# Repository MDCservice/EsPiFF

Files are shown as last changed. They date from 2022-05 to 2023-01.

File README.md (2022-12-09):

# EsPiFF
An ESP32 in the Raspberry Pi form factor

## Meet the EsPiFF - The ESP32 in the Raspberry Pi 4 form factor

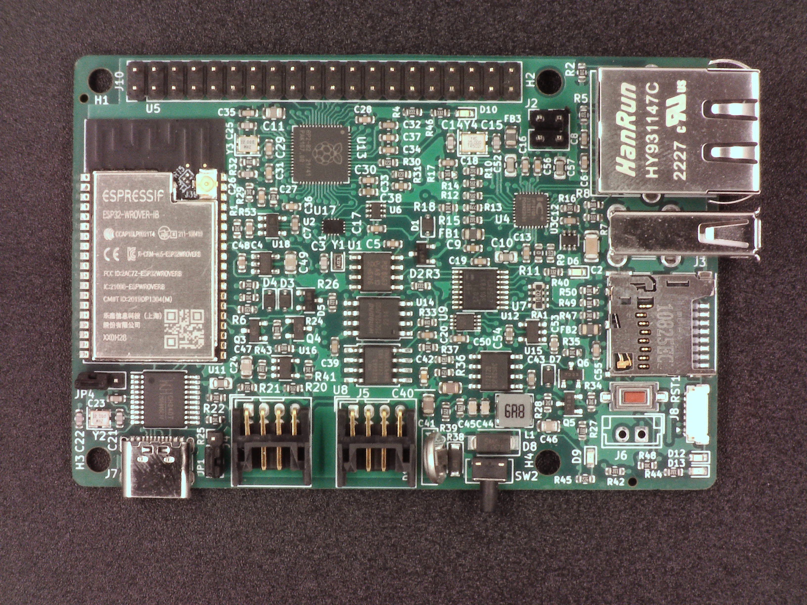
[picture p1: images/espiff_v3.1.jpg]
The EsPiFF


For applications, where the Raspberry Pi 4 is not robust enough, or take too much power, you can consider the EsPiFF as an option.
The EsPiFF (V2) brings
 - ESP32-WROVER with dual core, 8MB PSRAM, 16 MB Flash
 - Ethernet wired and Wifi (Wifi need an external antenna with an uFL connector)
 - SD-card for data storage
 - up to 3 UARTs
 - an USB-C connector for power supply up to 5V, 3A
 - a Rasperry Pi header with 40 pin, compatible to all Raspberry Pi HATs

The EsPiFF V3 will bring the following 
 - an RP2040 IO-processor additional to the ESP32
 - 2kByte FRAM for high-speed permanent storage
 - RTC Realtime clock
 - USB-A connector for USB-Host

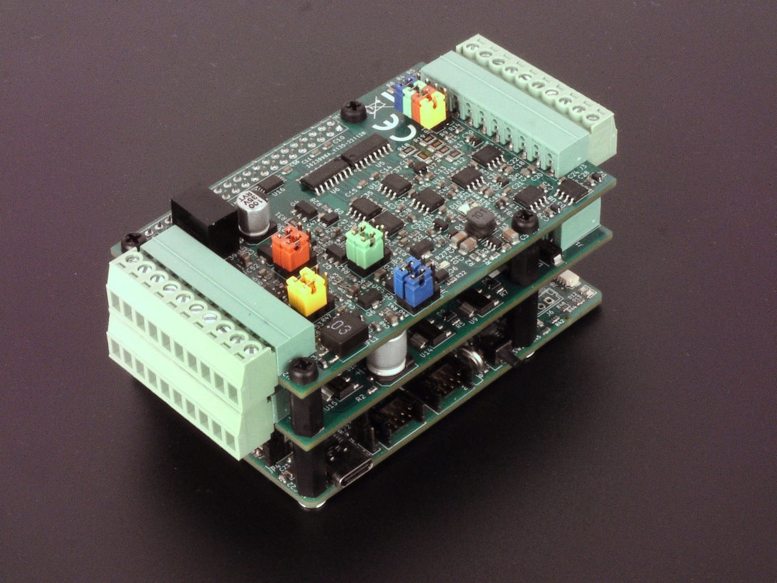
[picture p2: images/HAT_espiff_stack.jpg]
HAT_dio

EsPiFF-PLC

## Why an ESP32 in the Raspberry Pi Form Factor?

We decided to build an alternative to the Raspberry Pi for our projects and products. As many others we were using the Raspberry Pi in our products, adding electronic payment to existing vending machines and coffee machines, in RFID solutions to read RFID tags in laundry and other application. 
While it was easy to get a solution up and running in a short time, over time we got a lot of problems resulting from using the Pi.
A key problem of the Pi's design is, to rely on an SD-card. The SD-cards are made for digital cameras, to write on them a few times. A Linux system like the Pi on the other hand, is writing permanent its log files and swap partition or to the SD-card. As a result, after some months the SD-card broke and the application crashed. High-end industrial SD-card lasted longer, but finally still broke. An industrial controller simply can not base on a SD-card.
The PI Operating system is also great for fast bring-up of a solution, but its more and more focused on media streaming then real-time tasks. It gets more and more overloaded with each new version.
So we made the decision, to build a replacement, which is focused on high-reliability, but still enable the use of Raspberry Pi universum of add-ons, like HATs and enclosures. We choose the ESP32 dual core, 2x240MHz WROVER module with 8MB PSRAM and 16MB Flash.  The EsPiFF, the **Es**p32 in Raspberry **Pi** **F**orm **F**actor was born.

## History
### Version 1
The first version of the EsPiFF was born in a time, where all Ethernet Phy chips was unavailable. Our first prototype used a Waveshare LAN8720 module. Chip crysis! Interestingly, even no LAN8720 chips could be bought anywhere, but the modules was still available. Because the Waveshare module did not route the enable signal to the pin header, but left one pin unconnected on the pin header, we had to solder a wire from the oscillator to that unused pin on the header. After these, the board run well, and do so till now. We added 4 high side switches, and digital inputs to operate 4 door locks. These are the 4 white connectors opposite the RJ45 connectors. The Version 1 had the WROOM module of the ESP32.  

Picture: the Version 1 of the EsPiFF

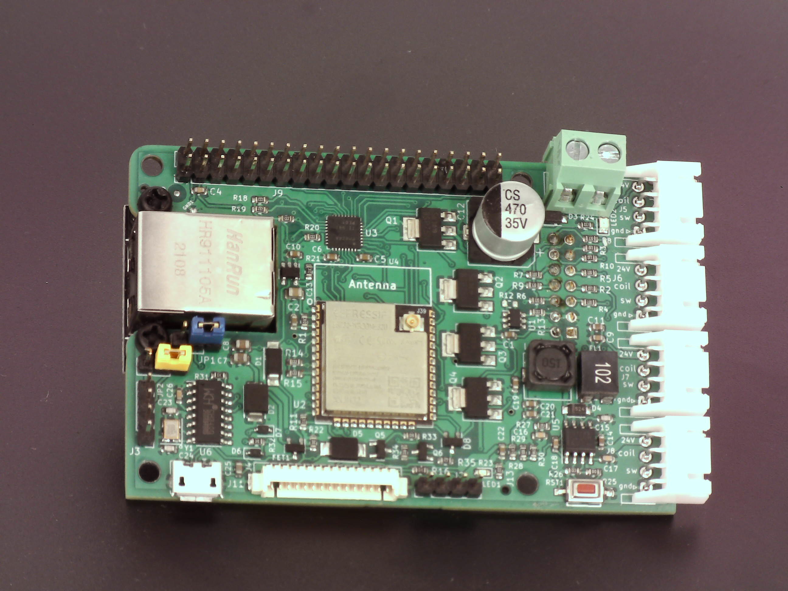
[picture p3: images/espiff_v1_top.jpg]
The Version 1


We ported the PostgreSQL client libray, based on [SimplePgPSQL](https://github.com/ethanak/SimplePgSQL) to the EsPiFF, what worked very well, even with the limited RAM and Flash. Not only SELECT, INSERT and UPDATE work, but also the brilliant PostgreSQL feature NOTIFY. As a result, the EsPiFF dont need to poll the PostgreSQL server, but get notified instead. We could define a trigger in PostgreSQL, and notify other EsPiFF board. Thats very cool.

Because of the ongoing chip crysis, we only select parts, what are available. 

### Version 2

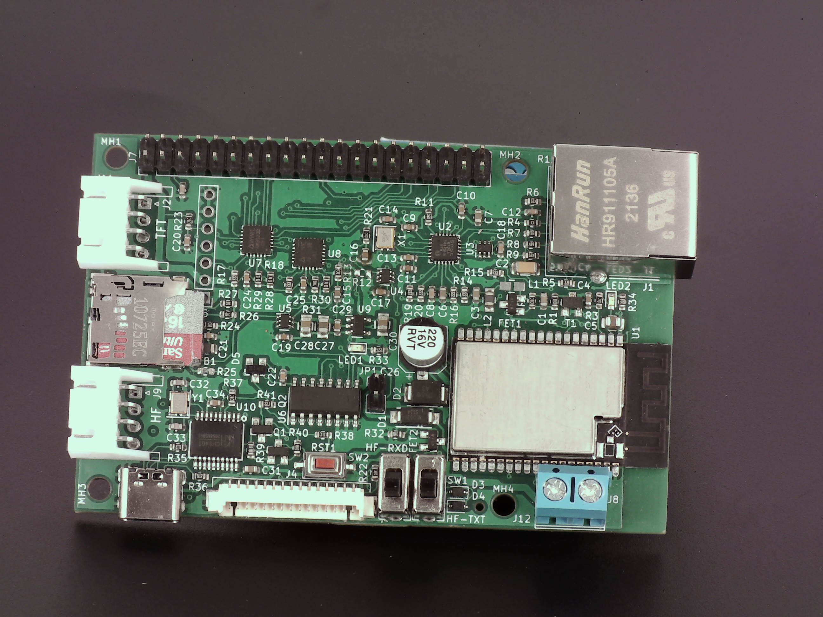
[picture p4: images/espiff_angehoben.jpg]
The Version 2
 
After the LAN8720 chips got available again, we decided to make a new board revision. These are the current boards. We used the ESP32-WROVER module, for additional 8MB PSRAM and 16MB Flash. We also added an SD-card. Unfortunately, we used the wrong pinout, make it very difficult to change the SD-card. An other issue was a missing pull-up resistor on the LAN8720. 
We changed the USB connector to a Type-C connector, and configured it so, that 5V and up to 3A can be taken. Thats a big improvement, raising the available power from 0.5W to 15W. We removed the 4 door lock connectors, and put them on a HAT. 
Since version 1 we have a "Chafon-Connector", next to the USB connector. It is to connect the Chafon RFID Rain(UHF) modules. Additional, we replaced the UART pin headers with more robust JST connectors, left and right of the SD-card. 

We could also compile and flash the Apache Nuttx operating system on the new board. A growing number of people are using ESP32-WROVER boards together with Nuttx as OS. This offers an somehow easy path of porting Linux and Raspberry Pi software on ESP32+Nuttx. 

### Version 3
This is the planned final version. Additional to the fix of the 2 known issues, we plan the following:
 - adding a I2C-RTC: a real-time clock will be needed for planned PLC usage.
 - adding a 2kByte FRAM: again for PLC application, a fast and non-volatile memory is needed. It offers near infinity write/read cycles compared to flash.
 - replace the WROVER module with a version with u.FL/IPEX connector. This enables an external antenna, longer range, mounting inside a metal enclosure with the antenna outside the enclosure.
 - adding a RP2040 co-processor. The ESP32 just not have enough pins free, to operate all the pins on the Raspberry Pi 40pin header. The last solution with the I2C port expander is too slow and unflexible. The much more powerfull RP2040 will solve these problem. It also offers an USB host port!
 - add a USB-A connector, to program the RP2040, and to enable to connect USB devices like keyboard, mouse, USB-sticks and so on. 
 - add an HMI connector next to the SDcard socket. This is for our upcomming TFT displays, but can be used for UART based TFTs like the Nextion as well. 

This is the current progress. We managed, to bring all the functionality on the board. We selected a 6 layer PCB, for best signal integrity.

The ESP32 can communicate with the RP2040 via SPI, where the ESP32 is the SPI master. Depend on the requirements, the communication protocol can be implemented application specific, with ether the Espressif IDF or Arduino IDE. Or an existing SPI driver from, for example NuttX, could be used on the ESP side, and the RP2040 emulating for example an SD card or a SPI Flash.

One more option is to run [Firmata](https://github.com/firmata/ConfigurableFirmata) on the RP2040. This is a popular way for Arduino developers, to remote control and Arduino/RP2040 from a host computer, here the ESP32. For now, Firmata only supports UART communication, whats is also possible on the EsPiFF.

Because all pins on both the ESP32 and the RP2040 are used already, there are no decidated interupt pins between ESP32 and RP2040. The software should implement software interupts, when i.e. the receiving buffer reaches a certain level. 

The Version 3

We finally replaced the LAN8720 Ethernet PHY by an IP101, as used in the Espressif Ethernet reference design. The LAN8720 showed stability problems, in combination with the ESP32-WROVER (it is working well with the ESP32-WROOM). Other projects with the ESP32-WROVER - LAN8720 combination (wESP, Olimex) seem to had the same problems, and also switched away from the LAN8720. On this point, a big "Thank you" to Ondrej from Espressif for all of his support in this field. 

We also ordered customized cables, for the DF11 and display connectors, what offer DuPont on the opposite side. With these cables, breadbord or Nextion displays, or other 2.54mm headers can easily connected. 

## Typical applications

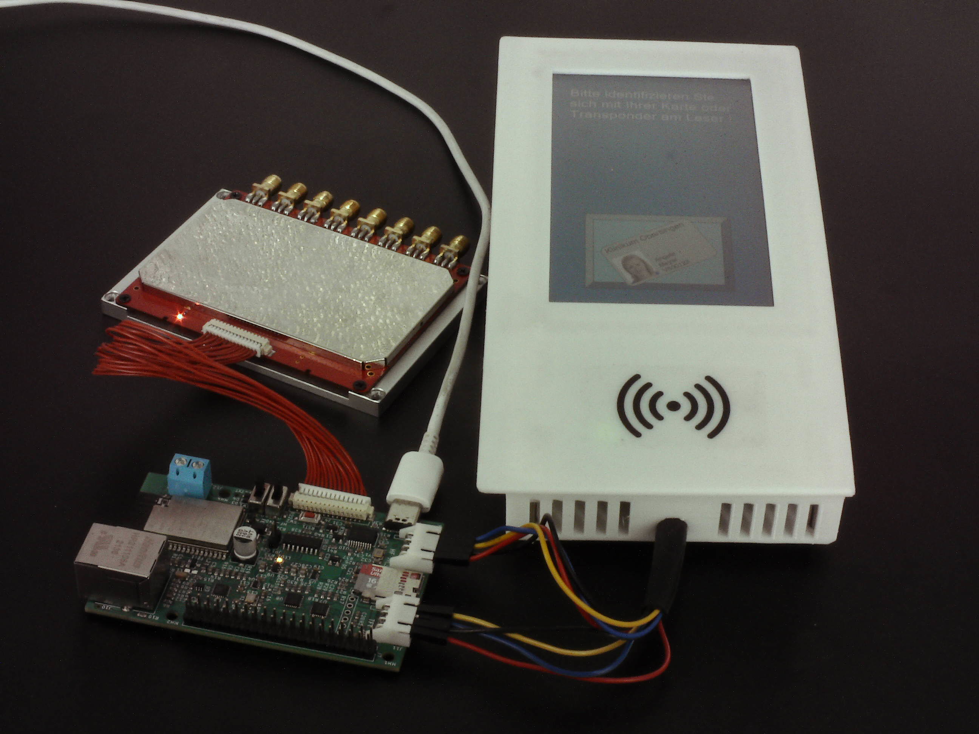
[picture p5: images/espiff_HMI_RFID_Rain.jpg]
HMI, RFID reader and EsPiff-V2


This example show, how a Nextion 5 inch TFT, a HF RFID reader from Elatec (TWN4), a Chafon 8 channel RAIN UHF-RFID reader and a 3D printed enclosure can form an electronic identification system. We put the source code and the 3D design files into the example folder. Smaller or bigger Nextion TFTs can be used, when you adapt the 3D design. 

The HMI interact with the user, ask him/her to put the HF-RFID card on the card reader. The TWN4 from Elatec is able to read near any LF or HF card, inclding the LEGIC chips used in many high secure access control applications. The TWN4 is inside the 3D printed enclosure, as well as the Nextion TFT.

With the 8 port RAIN UHF reader/writer from Chafon, we can monitor a whole area with up to 8 antennas. We use it to monitor 4 cabinets, other use cases could be the monitoring a whole room/warehouse, or the entrance of buiildings,etc. Chafon offer 1, 4, 8 and 16 port devices, and they are all compatible with the software. 

In our application, we read/write direct to a PostgreSQL database, connected by wired ethernet, thats why we have ported the LibPQ (the PostgreSQL client library) to the ESP32. The use of other techniques, like MQTT, is also possible. 

Picture: the open 3D printed enclsure, showing the Nextion 5'' TFT, and the TWN4 HF RFID reader
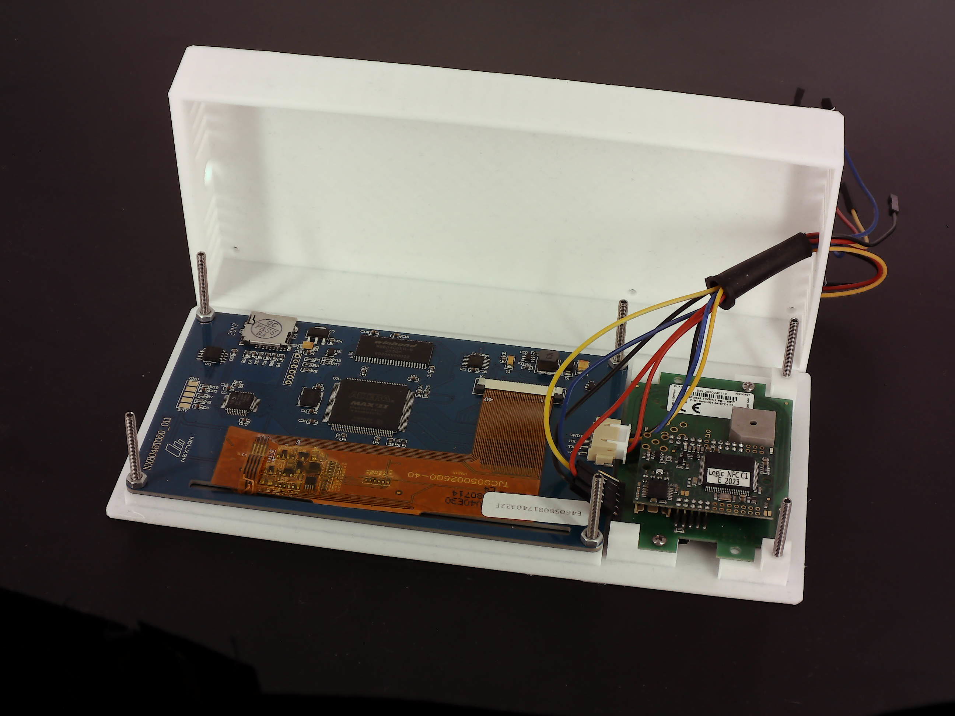
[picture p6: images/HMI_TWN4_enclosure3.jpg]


After the EsPiFF is now mature enough, we we are preparing a campaign at Crowd Supply. After the Pre-launch page will be available, we will update the info here. Hope you support us on our Crowd Supply campaign!

Please notice, that the ESP32-module PCB antenna can not be used, an external wifi antenna is required. This is because of space restrictions, the RasPi form factor not allow us to make the board larger, and there is simply no space left for the required keepout area for the PCB antenna. Most people will use a metal enclosure, what renders a PCB antenna useless anyway. We still have to use an ESP32-WROVER module containing a PCB antenna, because only these modules have 16 MB Flash, 8 MB PSRAM, and all the features we build in. Other modules, for example the ESP32-S3, does not have Ethernet MII. 

Apache Nuttx can run on the EsPiFF!
Next the wellknown FreeRTOS, there is an other, not so wellknown operating system supporting ESP32 and friends: Apache Nuttx (https://nuttx.apache.org).
It has a very cool feature: runtime loading of ELF files (for example, from SDcard) into RAM, and then execute it in RAM. Very much like Windows/Linux/MacOS are doing it. Imagine, you can send a SDcard to your customer for software-update. Bye bye over the air(OTA) updates in enviroments, where OTA is not allowed.

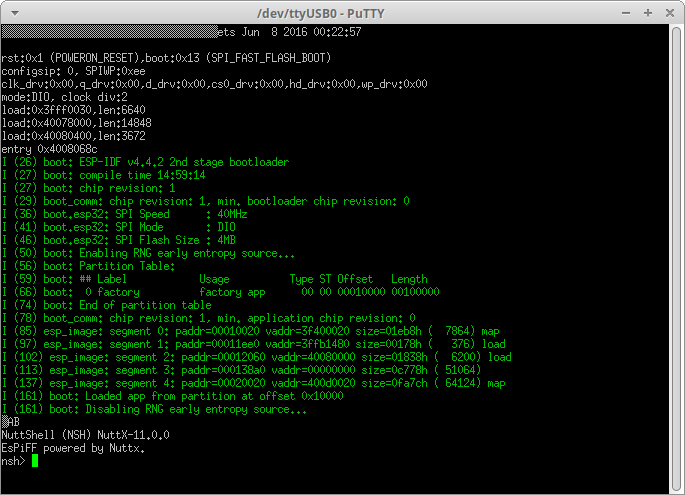
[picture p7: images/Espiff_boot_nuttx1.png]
Nuttx 11.0 on EsPiff-V3.1


ESP32 <> RP2040 interconnection

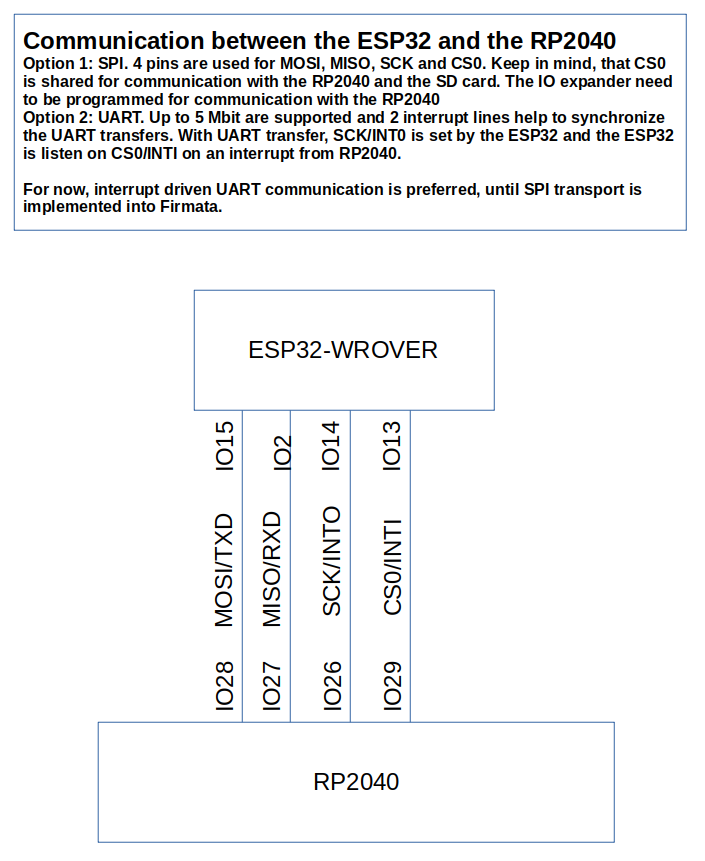
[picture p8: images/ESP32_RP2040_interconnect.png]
ESP32 <> RP2040


Latest news:
We just finish the layout of the version 3.2, the version the crowd supply backer will get. Few interesting things:
- We added not only Flash footprints for the ESP32, but also a footprint for an unpopulated SPI RAM for the RP2040. If you need up to 64 MBit SPI RAM for the RP2040, you can just mount an easy to solder SOIC-8 IC on the bottom, and you have 30 times(!) the RAM a normal RP2040 have. 

Because several people mention the integrated PCB antenna, the version 3.2 offer at least a basic use of the PCB antenna. Still, the external PCB antenna is the prefered way to use Wifi with the EsPiFF, now to use the integrated PCB antenna as well. 
Keep in mind, that the ESP32-WROVER-IB module requires a solder jumper modification before the PCB antenna can be used. 
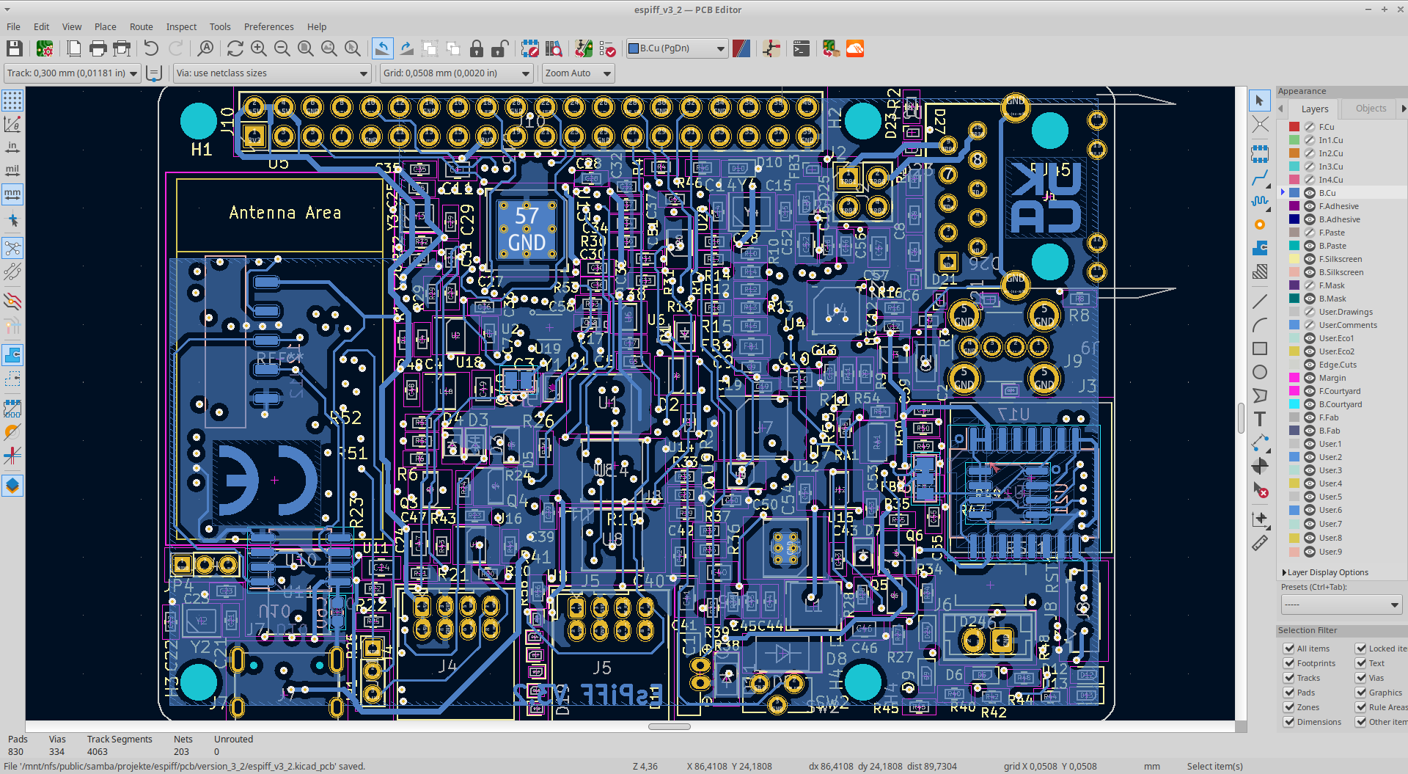
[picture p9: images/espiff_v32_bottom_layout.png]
ESP32 Wifi


Team MDC

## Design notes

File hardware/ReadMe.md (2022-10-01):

Hardware V3.1

This is the final schematic and layout for the Crowd Supply campaign.
The LAN8720 Ethernet PHY got replaced by the IP101, after the LAN8720 in combination with the ESP32-WROVER was not working stable.
Additionally, we added an TFT-Display connector for serial displays/HMIs.

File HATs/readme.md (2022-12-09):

**HATs for the EsPiFF**

****Digital IO HAT****
DIO

The Digital IO HAT offers 8 individual configurable digital inputs or outputs. Each of the 8 DIO pins can be configured by software to be ether an digital output with up to 1.2A, or an digital input for voltages from 3.3V to 30 Volt. All inputs and outputs are protected against over-voltage, over-current and over-temperature, additional protection for voltage spikes(up to 4kV) and static discharge is build in as well. 

Inputs can be read with up to 1 MSps, the outputs can be set with up to 6kHz. The digital IO part is complete galvanic isolated from the EsPiFF, with 6mm creepage distance between the logic part and IO part. 

With an external 24V power supply, the digital HAT powers it self and the EsPiFF(or Pi Nano). If no external power is supplied, the digital HAT receive its power from the EsPiFF(or Pi Nano).

The Digital IO HAT is made particular for the EsPiFF, because of its shape it can not be used with an Raspberry Pi 2/3/4. But it can be used with a Raspberry Pi Nano or Nano 2, and several Raspberry Pi clones. 

The 40 pin connector is build with extra long pins, so that an additional HAT can be stacked on it

****Analog IO HAT****
HAT_4ain_4aout

The analog IO HAT offers 4 analog inputs and 4 analog outputs. Each input and output can be jumper configured for ether 4-20mA or 0-10V signals. The analog inputs are synchronous sampled by 16 bit ADCs, the analog outputs are synchronous set by 12 bit DACs. 

The ADCs are build by analog-to-PWM converters, to allow syncron sampling and save galvanic isolation. For the same reason, the DACs are build by PWM-to-analog converters. This offers the unique feature, that all analog inputs and outputs can be synchronous set with ns accuracy, what typical SPI or I2C based  converters can never offer. To read and set the converters, 4 PWM cannals, and 4 Pulse width measurement units are needed. This is a perfect job for the PIOs of the EsPiFF. A Raspberry Pi offer only 2 (hardware) PWM channels, so a PI would not be a good platform for this kind of converters.

Extra care has been taken to implement a low noise power supply: a galvanic isolated PSU module generates 15 Volt. A team of ferrite beads, common mode chokes and ultra low noise linear regulators filter out all noise from the switching regulators and outside world. Only this very careful design enables 15 bit net out of the 16 bit ADCs.  

****EsPiFF-PLC build from a EsPiFF, an digital and an analog HAT****
HAT_espiff_stack

With the analog and digital HAT, an EsPiFF transforms to a nice PLC. It is compact in size, low in price and profit from the EsPiFF reliability features.

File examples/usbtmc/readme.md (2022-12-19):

Convert every HAT to an USBTMC-Measurement device with the EsPiFF. 

** work in progress, might not compile on all platforms. We use Ubuntu 22 for development **

Instructions:
1. Download the Tinyusb github repo from https://github.com/hathach/tinyusb
2. Add a folder "espiff_usbtmc" under ./tinyusb/examples/device/
3. copy the files from EsPiFF/examples/usbtmc/ into the folder just created.
4. make sure, your PICO SDK is setup correctly.
5. follow the instructions from the TinyUSB repo to build.

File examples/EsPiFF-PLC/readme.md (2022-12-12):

**The EsPiFF-PLC**

Thanks to its reliability properties and its fast IO capacity, the EsPiFF is a great base for rock solid PLC (Pogrammable Logic Controller). We have made 2 HATs for the EsPiFF, what can be stacked on the EsPiFF, and an 3D printed enclosure, to use the EsPiFF as a PLC. Schematics for the digital HAT is here, for the analog HAT is here (Schematics are in alpha stage, because we could not yet test all functions).

To compare the EsPiFF-PLC with what the market offer, lets compare the EsPiFF-PLC with 2 popular PLCs, one from the Arduino base ([Industruino](https://industruino.com/)) and an other from Raspberry Pi base ([Pixtend](https://www.pixtend.de/pixtend-v2/hardware-v2) V2 -S-). We have worked with both of them, before we decided to make the EsPiFF. Finally, I added the brand new Arduino Opta for comparison.

We do not cover PLCs without C/C++ programming, because Ladder Logic/FBD/ST from companies like Siemens, ABB, Rockwell, Mitsubishi etc. is out of the scope for most makers. Also most of them require an initial investment of several thousand $$ for there proprietary IDE / tools, before you can even start. 

## Comparisons

| | EsPiFF-PLC | Industruino | Pixtend-V2 -S- | Arduino Opta |
| --- | --- | --- | --- | --- |
| **PLC processor** ~active  | RP2040 | ATSAMD21G | ATMega324A | STM32H747XI | 
| **Digital inputs** | Up to 8 | Up to 8 | 8 | 8 |
| **Digital outputs** | Up to 8 | Up to 8 | 4 | 0 |
| **Digital block isolated** | Yes | Yes | No | No |
| **Analog inputs** | 4 (16 bit) | 4 (18 bit) | 2 (10 bit) | up to 8 |
| **Analog outputs** | 4 (12 bit) | 2 (12 bit) | 2 (V only) | None |
| **Analog block isolated**  | Yes | Yes | No | No |
| **Relay outputs** | 2 | 0 | 4 | 4 |
| **Retain memory** | 2 kBytes | 0 | 32 Bytes | 0 |
| **External RTC** | Yes | Yes | Yes | unknown |
| **External supervisior** | Yes | No | No | unknown |
| **Buffered RTC** | Yes | No | Yes | unknown |
| **PLC processing** | 2x133 MHz | 48 MHz | 20 MHz | 240 MHz |
| **Ethernet** | Yes | External (via SPI) | Yes | Yes |
| **Price** | $169.00 | $272.72 | $279.21 | $177.10 |

Its clear, that both competitors have serious limitations: The Pixtend have no galvanic isolation, only 4 digital outputs, only 10 bit analog inputs and  analog output. So its impossible to drive 4 - 20mA actuators like proportional valves. The analog resolution with just 10 bit ADCs does not allow accurate measurements, what limit its usefulness to a few low resolution applications. 
While the Pixtend offers enoumous processing power on the Raspberry Pi side, the real time processing power is very limited by the 8 bit ATMega324. As a result, no more then 500 to 800 cycles per second are possible (In a PLC, in one cycle all inputs are read and all output are set). The analog inputs have a "Cut-off frequency of 275 Hz", so my guess would be the analog inputs are limited to 100-150Hz.  A demanding servo application can not be build with this. The Retain memory memory is only guarantied for 10.000 write operation, the datasheet discourage the use of it (the FRAM on the EsPiFF guaranties 10 billion write cycles!). Finally the Pixtend is closed source, and Pis are not available because of the chip shortage. 

The Industruino is simple, easy to program, have 4 analog input with 18 bit, 2 analog output (12 bit), 8 digital IOs (each can be input or output), external RTC. Sound good until now. But: 
- No battery or capacitor to keep the RTC when power is removed,  
- no external supervision, 
- you need to buy the external Ethernet module, to get Ethernet, a socket for an FRAM, SD card socket. 
- only for a few parts schematics are open source,  
- a single  ATSAMD21G with 48MHz, 32 kByte RAM, 256kByte Flash must do all the work.
- quit expensive for the little functionality
- can NOT be programmed in Python

What the Pixtend had too much on processing power, the Industruino have too little. When you run a Modbus server, the MCU is mostly busy with network traffic. 

When we see the 500 to 800 cycles on the Pixtend as slow, it gets even worse with the  Industruino: the ADC on the Industruino is a MCP3424 I2C, what offer 3.75 SPS (18 bits), 15 SPS (16 bits), 60 SPS (14 bits) and 240 SPS (12 bits). SPS means "Samples Per Second". There will be applications, what are possible within these limits. But hey, that can be done better.

Just for reference, lets also take a look at the brand new Arduino Opta. It does not have analog outputs, not even digital outputs, so its usefulness is very limited. The concept of the Opta with a dual core controller is good, to seperate IO processing from network processing. Having relays integrated into the PLC is not often used, for a good reason: Users can simply install as many relays they need on a Din Rail, and choose the exact relay type they need for the particular application. Then control the relay with a digital output of the relay.

DinRailRelay

The relays in the Opta are only SPST (single pole, single throw, 2 contacts each), but many applications need a 3 contact version to flip between NC and NO. If you look at the [DIN Rail relay selection on Mouser](https://www.mouser.de/c/electromechanical/relays-contactors-solenoids/general-purpose-relays/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), you see how many configurations are possible. Interesting to see, that Arduino move to closed source and pay-to-use software with there PLC products: "runtime activation for each device will require a license key". Bye bye open source Arduinos.  

We have 2 HATs for the EsPiFF, one analog and one digital HAT. Together with the EsPiFF, they form the ***EsPiFF-PLC***. At the moment, the hardware just arrived, the software need some time to arrive at the EsPiFF github. 

****EsPiFF-PLC****
HAT_espiff_stack

****digital IO HAT****
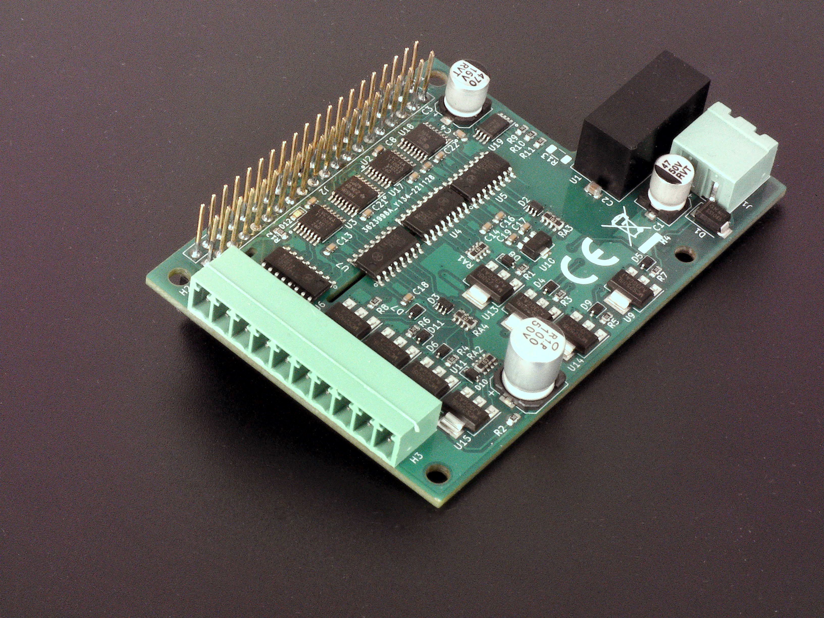
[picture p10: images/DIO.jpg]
HAT_dio


****analog IO HAT****
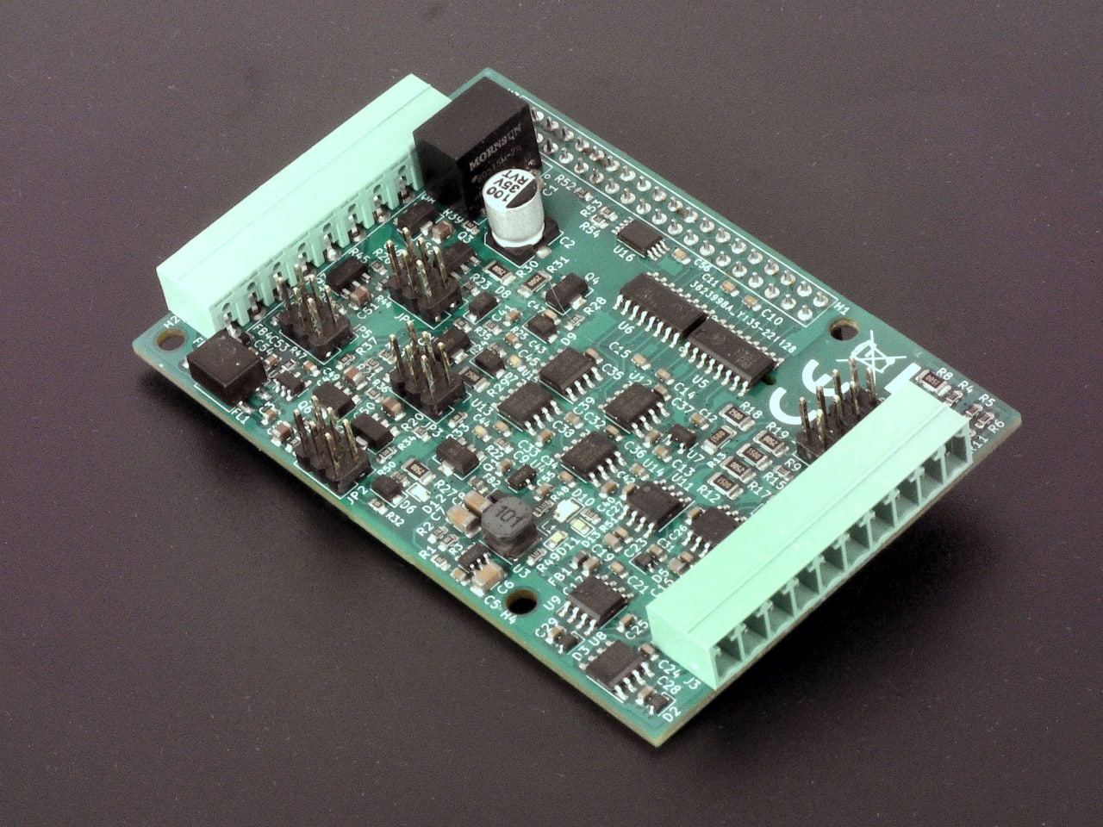
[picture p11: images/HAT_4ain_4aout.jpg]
HAT_analog


These 2 HATs are particular made for the EsPiFF: Even they could mechanically be mounted on a Raspberry Pi Nano, only the RP2040 PIOs have enough PWM channels and pulse-width measurement resources to operate the analog HAT. 

The HATs are stacked on the 40 pin Header, and are all controlled by the RP2040 from the EsPiFF. There is a detailed description about the HATs [on the EsPiFF github](https://github.com/MDCservice/EsPiFF/blob/main/HATs/readme.md), so I don't repeat that here.  Just the key facts:

4 analog in, jumper select-able for 0 to 10V or 4 - 20mA, fully protected.
4 analog out,  jumper select-able for 0 to 10V or 4 - 20mA, over-current, over-temperature, over-voltage protected.
All analog parts are galvanic isolated from the EsPiFF and the digital section.
8 digital IOs, each individual configurable as input or output, fully protected. As output, they can sink up to 1.2A permanent each, up to 32 Volt.  
All digital IOs are galvanic isolated from EsPiFF and from the analog section.  

The RP2040 as PLC-IO processor have multiple times the processing power, RAM and Flash, compared to the ATSAMD21G on the Industruino or the ATMega324 on the Pixtend. 16 MB Flash compared to 256kB(Industruino) or 32kB(Pixtend) result in 64/512 times bigger application. If the 16 MB additional SPI-RAM is soldered on the EsPiFF, the RP2040 on the EsPiFF have 512 times the RAM of an Industruino and 8192 times the RAM of the ATMega324 on the Pixtend.

Having the network stuff handled by its own processor unit, frees the PLC processor from these time consuming work. This is given on the EsPiFF-PLC by the ESP32, as well as on the Pixtend. But just the EsPiFF is build for reliability with external supervisior, external watchdog, and a real RTOS. 

Speed: we see, even with its enormous processing power of a Rasperry Pi, the Pixtend can maximal reach a cycle time of up to 800 per second. The Industruino is limited by its ADC to 240 cycles per second at low resolution ADC or 3.75 cycles per second at high resolution ADC. Here are the EsPiFF numbers:

- Digital inputs: up to 50.000  cycles per second.
- Digital outputs: up to 6.000 cycles per second.
- Analog inputs: up to 10.000 cycles per second. 
- Analog outputs: up to 50.000 cycles per second.

For the Pixtend, we know the limit of 800 cycles ([the Handbook suggest only 10Hz!](https://www.pixtend.de/files/manuals/AppNote_CodesysPiXtendProject_DE.pdf)), for the Industruino we [know the limit of 1380Hz](https://industruino.com/forum/help-1/question/speed-problem-on-i-o-board-100). Just in real world applications, the Industruino will not reach these limits, because as long as its answering network packages, the single core can not operate IOs at the same time. The unpredictable network processing load will also lead to unpredictable real time behavior. For the Arduino Octa, no data or experience are available.  

Finally, lets look at a typical PLC application: reading an 4-20mA transducer, performing a PID control algorithm, and set a new analog value on the 4-20mA output. I used to implement this exact scenario for a hydraulic pressure test bench a few years ago. An hydraulic pressure transducer transmitted a 4-20mA signal for the hydraulic pressure on the hose under test to the analog input, the pressure actor was commanded with an 4-20mA analog output and a PID control algorithm set the current test pressure. The Arduino Octa have no analog or digital outputs, so its out of the game here. Lets see, how many such control loops the EsPiFF-PLC and the 2 competitors can handle per second:  

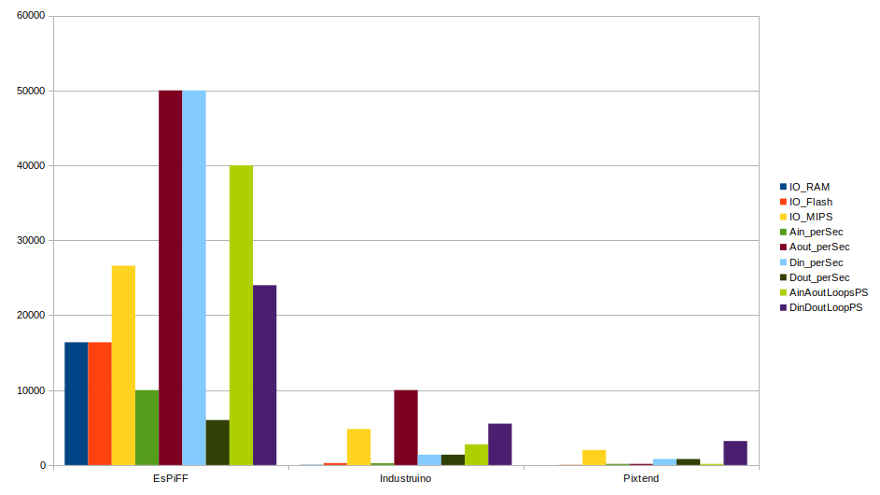
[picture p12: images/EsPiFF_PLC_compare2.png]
Compare_loops_perSecond


The EsPiFF-PLC is more then 14 times faster in analog processing then the Industruino; the Pixtend is out of this game because it does not offer an analog 4-20mA output. 
In a pure digital loop (read digital in, compute, set digital out), the EsPiFF is still more then 4 times faster then the Industruino and more then 7 times faster then the Pixtend. 

We hope, this article shows, how powerful the EsPiFF is.

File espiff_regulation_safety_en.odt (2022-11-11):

EsPiFF REGULATORY COMPLIANCE AND SAFETY INFORMATION

Product name: EsPiFF V3.2

IMPORTANT: PLEASE RETAIN THIS INFORMATION FOR FUTURE REFERENCE

Getting Started

For full set up and installation instructions please visit https://github.com/MDCservice/EsPiFF/tree/main/examples

Warnings

- This product shall only be connected to an external power supply ether rated at 5V dc, and a minimum current of 300-1800mA, if power is supplied by USB-C. If powered by the 24V pin header, an external power supply rated from 9V to 32V and minimum current of 200mA must be used. Any external power supply used with the EsPiFF shall comply with relevant regulations and standards applicable in the country of intended use.
- This product should be placed on a stable, flat, non-conductive surface in use and should not be contacted by conductive items.
- The connection of unapproved devices to the GPIO connector may affect compliance or result in damage to the unit and invalidate the warranty.
- All peripherals used with the EsPiFF should comply with relevant standards for the country of use and be marked accordingly to ensure that safety and performance requirements are met. These articles include but are not limited to keyboards, monitors, and mice used in conjunction with the EsPiFF.
- Where peripherals are connected that do not include the cable or connector, the cable or connector used must offer adequate insulation and operation in order that the requirements of the relevant performance and safety requirements are met.

Instructions for safe use

To avoid malfunction or damage to your EsPiFF please observe the following:

- Do not expose it to water, moisture or place on a conductive surface whilst in operation.
- Do not expose it to heat from any source; the EsPiFF is designed for reliable operation at normal ambient room temperatures.
- Take care whilst handling to avoid mechanical or electrical damage to the printed circuit board and connectors.
- Avoid handling the printed circuit board while it is powered. Only handle by the edges to minimize the risk of electrostatic discharge damage.
- The EsPiFF is designed to be powered from a USB port, from a PoE HAT or the 24V pin header. Do not power the EsPiFF by other means.

Compliance information

The EsPiFF complies with the relevant provisions of the RoHS Directive for the European Union. In common with all Electrical and Electronic Equipment (EEE) the EspiFF should not be disposed of as household waste. Alternative arrangements may apply in other jurisdictions.

Electromagnetic compatibility and operation

- This product is in conformity with the protection requirements of EU Council Directive 2004/108/EC on the approximation of the laws of the Member States relating to electromagnetic compatibility.
- This product has been tested and found to comply with the limits for Class B Information Technology Equipment according to the European Standard. NOTE: This equipment has been tested and found to comply with the limits for a Class B digital device, pursuant to part 15 of the FCC Rules. These limits are designed to provide reasonable protection against harmful interference in a residential installation. This equipment generates, uses and can radiate radio frequency energy and, if not installed and used in accordance with the instructions, may cause harmful interference to radio communications. However, there is no guarantee that interference will not occur in a particular installation. If this equipment does cause harmful interference to radio or television reception, which can be determined by turning the equipment off and on, the user is encouraged to try to correct the interference by one or more of the following measures: - Reorient or relocate the receiving antenna - Increase the separation between the equipment and receiver - Connect the equipment into an outlet on a circuit different from that to which the receiver is connected
  - Consult the dealer or an experienced radio/TV technician for help
  WARNING: Please do not alter or modify the design of this product, doing so may void your ability to use the product freely, this includes altering the frequency at which the product operates.

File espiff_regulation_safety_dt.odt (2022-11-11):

EsPiFF Gesetzliche Vorschriften und Sicherheitsinformationen

Produktname: EsPiFF V3.2

Wichtig: Bitte bewahren Sie diesen Merkzettel gut auf, um auch in Zukunft nachzulesen.

Einstieg / Erste Schritte

Für eine vollständige Anleitung lesen Sie bitte diese Informationen:

https://github.com/MDCservice/EsPiFF/tree/main/examples

Warnungen

- Dieses Produkt darf nur mit einer externen Stromversorgungen betrieben werden, die entweder spezifiziert ist als 5V Gleichspannungsnetzteil, und für eine minimalen Strom von 300 – 1800mA spezifiziert ist, wenn die Stromversorgung über die USB-C Buchse erfolgt.
  Soll die Stromversorgung über den 24V Pin Stecker erfolgen, so muss diese für einen Spannungsbereich von 9V bis 32V und mindestens für 200mA spezifiziert sein. Jede externe Stromquelle muss den relevanten gesetzlichen Bestimmungen des Landes entsprechen, in dem diese eingesetzt wird.
- Dieses Produkt sollte während des Gebrauchs auf einer stabilen, flachen, nicht leitfähigen Oberfläche platziert werden und darf nicht mit leitenden Gegenständen in Kontakt gebracht werden.
- Der Anschluss nicht zugelassener Geräte an den GPIO-Anschluss kann die Konformität beeinträchtigen oder zu Schäden am Gerät führen und die Garantie ungültig machen.
- Alle mit dem EsPiFF verwendeten Peripheriegeräte sollten den einschlägigen Normen des Verwendungslandes entsprechen und entsprechend gekennzeichnet sein, um sicherzustellen, dass die Sicherheits- und Leistungsanforderungen erfüllt werden. Diese Artikel beispielsweise HATs, Monitore und Mäuse, sowie sonstige Peripherie die mit dem EsPiFF verwendet werden.
- Wenn Peripheriegeräte angeschlossen werden, die kein normgerechtes Kabel oder Stecker enthalten, muss das verwendete Kabel oder Leiter eine angemessene Isolierung und Betriebsfunktion bieten, damit die Anforderungen der relevanten Leistungs- und Sicherheitsanforderungen erfüllt werden.

Hinweise zur sicheren Benutzung

Um Fehlfunktionen oder Schäden an Ihrem EsPiFF zu vermeiden, beachten Sie bitte folgende Hinweise:

- Setzen Sie den EsPiFF während des Betriebs weder Wasser noch Feuchtigkeit aus und legen Sie es nicht auf eine leitfähige Oberfläche.
- Setzen Sie den EsPiFF keiner Wärme- oder Hitzequelle aus; Der EsPiFF ist für einen zuverlässigen Betrieb bei normalen Raumtemperaturen ausgelegt.
- Gehen Sie bei der Handhabung vorsichtig vor, um mechanische oder elektrische Schäden an der Leiterplatte und den Anschlüssen zu vermeiden.
- Vermeiden Sie es, die Leiterplatte zu bewegen, während diese eingeschaltet ist. Bitte berühren Sie die Platine nur an den Kanten, um das Risiko einer Beschädigung durch elektrostatische Entladung zu minimieren.
- Das EsPiFF ist so konzipiert, dass es über einen USB-Anschluss, einen PoE-HAT oder die 24-V-Stiftleiste mit Strom versorgt wird. Versorgen Sie das EsPiFF nicht auf andere Weise mit Strom.

Konformitätserklärung

Der EsPiFF entspricht den einschlägigen Bestimmungen der RoHS-Richtlinie für die Europäische Union. Wie alle Elektro- und Elektronikgeräte (EEE) darf auch der EspiFF nicht im Hausmüll entsorgt werden. Außerhalb der Europäische Union können alternative Regelungen gelten.

Elektromagnetische Verträglichkeit und Betrieb

- Dieses Produkt entspricht den Anforderungen der EU-Richtlinie 2004/108/EG des Rates zur Angleichung der Gesetze der Mitgliedstaaten über die elektromagnetische Verträglichkeit.
- Dieses Produkt wurde getestet und entspricht den Grenzwerten für informationstechnische Geräte der Klasse B gemäß der europäischen Norm.
- HINWEIS: Dieses Gerät wurde getestet und entspricht den Grenzwerten für ein digitales Gerät der Klasse B gemäß Teil 15 der FCC-Bestimmungen. Diese Grenzwerte sollen einen angemessenen Schutz vor schädlichen Interferenzen bei einer Installation in Wohngebieten bieten. Dieses Gerät erzeugt, verwendet und kann Hochfrequenzenergie ausstrahlen und kann, wenn es nicht gemäß den Anweisungen installiert und verwendet wird, schädliche Störungen des Funkverkehrs verursachen. Es gibt jedoch keine Garantie dafür, dass bei einer bestimmten Installation keine Interferenzen auftreten. Wenn dieses Gerät schädliche Störungen beim Radio- oder Fernsehempfang verursacht, was durch Ein- und Ausschalten des Geräts festgestellt werden kann, wird dem Benutzer empfohlen, zu versuchen, die Störung durch eine oder mehrere der folgenden Maßnahmen zu beheben: - Richten Sie die Empfangsantenne neu aus oder positionieren Sie sie neu, - Vergrößern Sie den Abstand zwischen Gerät und Empfänger, - Verbinden Sie das Gerät mit einer Steckdose in einem anderen Stromkreis als dem, an den der Empfänger angeschlossen ist,
  - Wenden Sie sich an den Händler oder einen erfahrenen Radio-/Fernsehtechniker, um Hilfe zu erhalten
  WARNUNG: Bitte ändern oder modifizieren Sie nicht das Design dieses Produkts, da dies Ihre Fähigkeit zur freien Verwendung des Produkts beeinträchtigen kann. Dazu gehört auch die Änderung der Frequenz, mit der das Produkt arbeitet. Verwenden Sie nur die beigelegte Antenne.

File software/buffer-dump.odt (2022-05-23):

0000 52 R 00 00 00 08 00 00 00

0008 00 53 S 00 00 00 1E 61 a 70 p

0010 70 p 6C l 69 i 63 c 61 a 74 t 69 i 6F o

0018 6E n 5F _ 6E n 61 a 6D m 65 e 00 53 S

0020 63 c 61 a 6C l 61 a 64 d 69 i 73 s 00

0028 53 S 00 00 00 19 63 c 6C l 69 i

0030 65 e 6E n 74 t 5F _ 65 e 6E n 63 c 6F o

0038 64 d 69 i 6E n 67 g 00 55 U 54 T 46 F

0040 38 8 00 53 S 00 00 00 17 44 D

0048 61 a 74 t 65 e 53 S 74 t 79 y 6C l 65 e

0050 00 49 I 53 S 4F O 2C , 20 4D M 44 D

0058 59 Y 00 53 S 00 00 00 19 69 i

0060 6E n 74 t 65 e 67 g 65 e 72 r 5F _ 64 d

0068 61 a 74 t 65 e 74 t 69 i 6D m 65 e 73 s

0070 00 6F o 6E n 00 53 S 00 00 00

0078 1B 49 I 6E n 74 t 65 e 72 r 76 v 61 a

0080 6C l 53 S 74 t 79 y 6C l 65 e 00 70 p

0088 6F o 73 s 74 t 67 g 72 r 65 e 73 s 00

0090 53 S 00 00 00 14 69 i 73 s 5F _

0098 73 s 75 u 70 p 65 e 72 r 75 u 73 s 65 e

00A0 72 r 00 6F o 6E n 00 53 S 00 00

00A8 00 19 73 s 65 e 72 r 76 v 65 e 72 r

00B0 5F _ 65 e 6E n 63 c 6F o 64 d 69 i 6E n

00B8 67 g 00 55 U 54 T 46 F 38 8 00 53 S

00C0 00 00 00 19 73 s 65 e 72 r 76 v

00C8 65 e 72 r 5F _ 76 v 65 e 72 r 73 s 69 i

00D0 6F o 6E n 00 31 1 31 1 2E . 31 1 32 2

00D8 00 53 S 00 00 00 20 73 s 65 e

00E0 73 s 73 s 69 i 6F o 6E n 5F _ 61 a 75 u

00E8 74 t 68 h 6F o 72 r 69 i 7A z 61 a 74 t

00F0 69 i 6F o 6E n 00 65 e 73 s 70 p 33 3

00F8 32 2 00 53 S 00 00 00 23 # 73 s

0100 74 t 61 a 6E n 64 d 61 a 72 r 64 d 5F _

0108 63 c 6F o 6E n 66 f 6F o 72 r 6D m 69 i

0110 6E n 67 g 5F _ 73 s 74 t 72 r 69 i 6E n

0118 67 g 73 s 00 6F o 6E n 00 53 S 00

0120 00 00 1B 54 T 69 i 6D m 65 e 5A Z

0128 6F o 6E n 65 e 00 45 E 75 u 72 r 6F o

0130 70 p 65 e 2F / 42 B 65 e 72 r 6C l 69 i

0138 6E n 00 4B K 00 00 00 0C 00

0140 00 93 � 2B + 83 � 82 � EE � 6E n 5A Z

0148 00 00 00 05 49 I 54 T 00 00

0150 00 1C 00 01 6E n 6F o 77 w 00

0158 00 00 00 00 00 00 00 00

0160 04 A0 � 00 08 FF � FF � FF � FF �

0168 00 00 44 D 00 00 00 26 & 00

0170 01 00 00 00 1C 32 2 30 0 32 2

0178 31 1 2D - 30 0 37 7 2D - 30 0 39 9 20

0180 31 1 32 2 3A : 31 1 32 2 3A : 34 4 34 4

0188 2E . 34 4 32 2 31 1 38 8 38 8 2B + 30 0

0190 32 2 43 C 00 00 00 0D 53 S 45 E

0198 4C L 45 E 43 C 54 T 20 31 1 00 5A Z

01A0 00 00 00 05 49 I

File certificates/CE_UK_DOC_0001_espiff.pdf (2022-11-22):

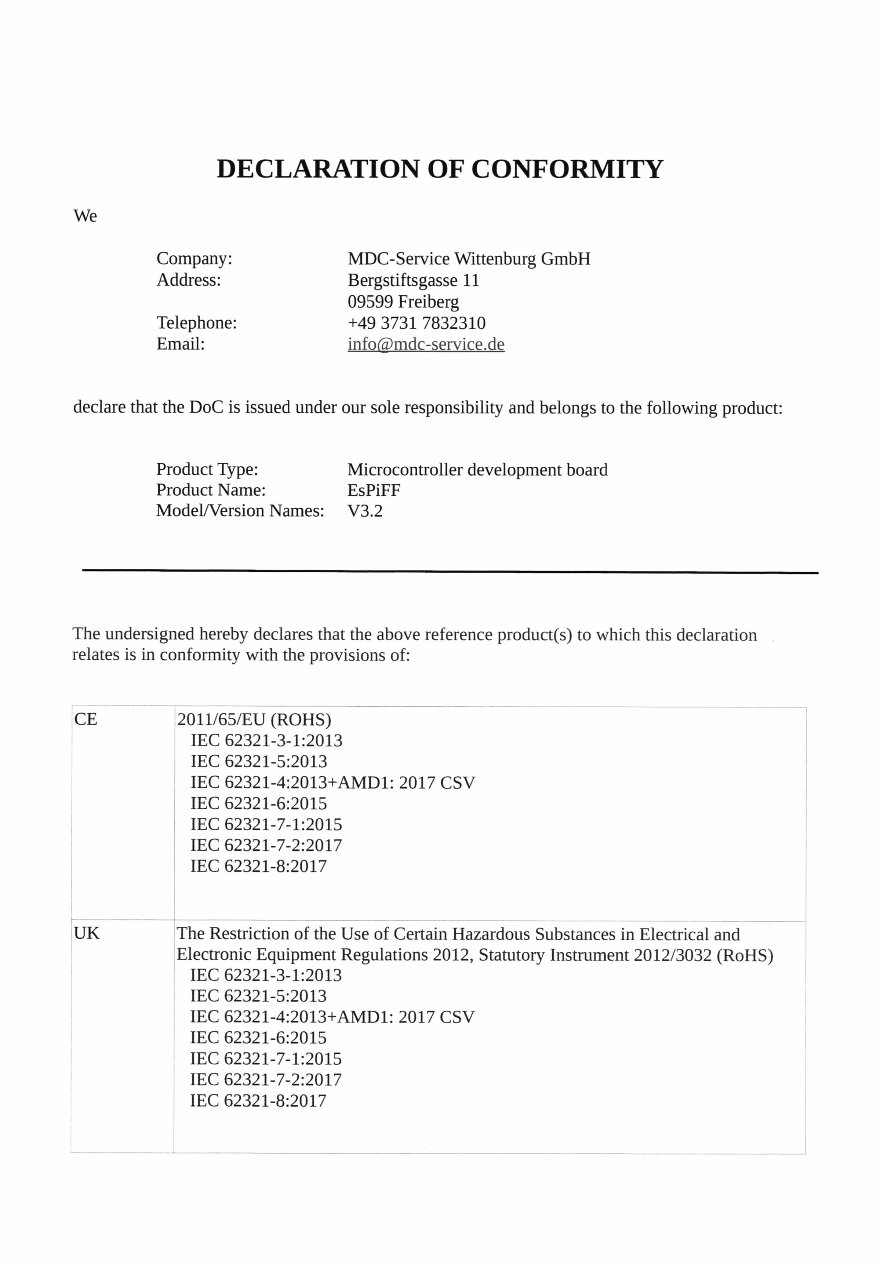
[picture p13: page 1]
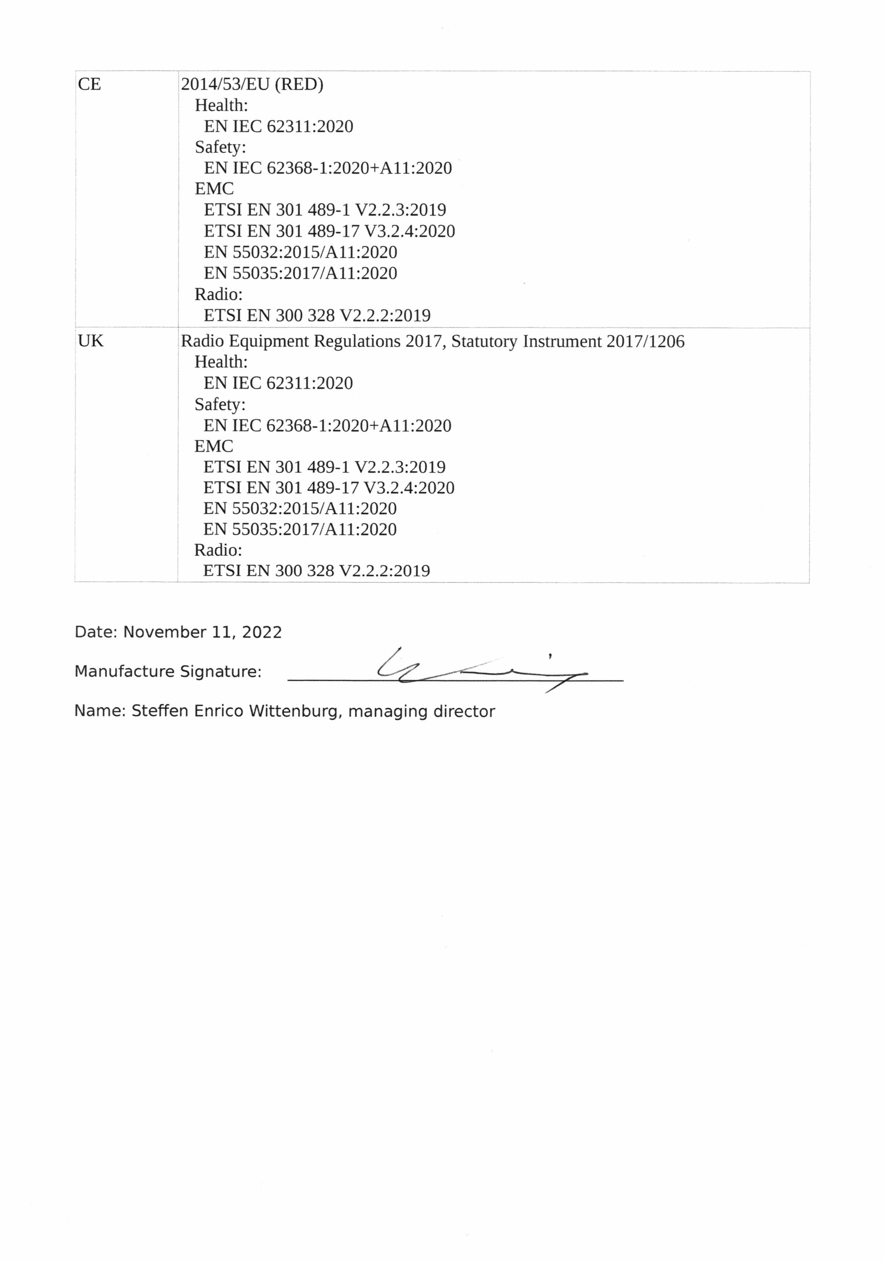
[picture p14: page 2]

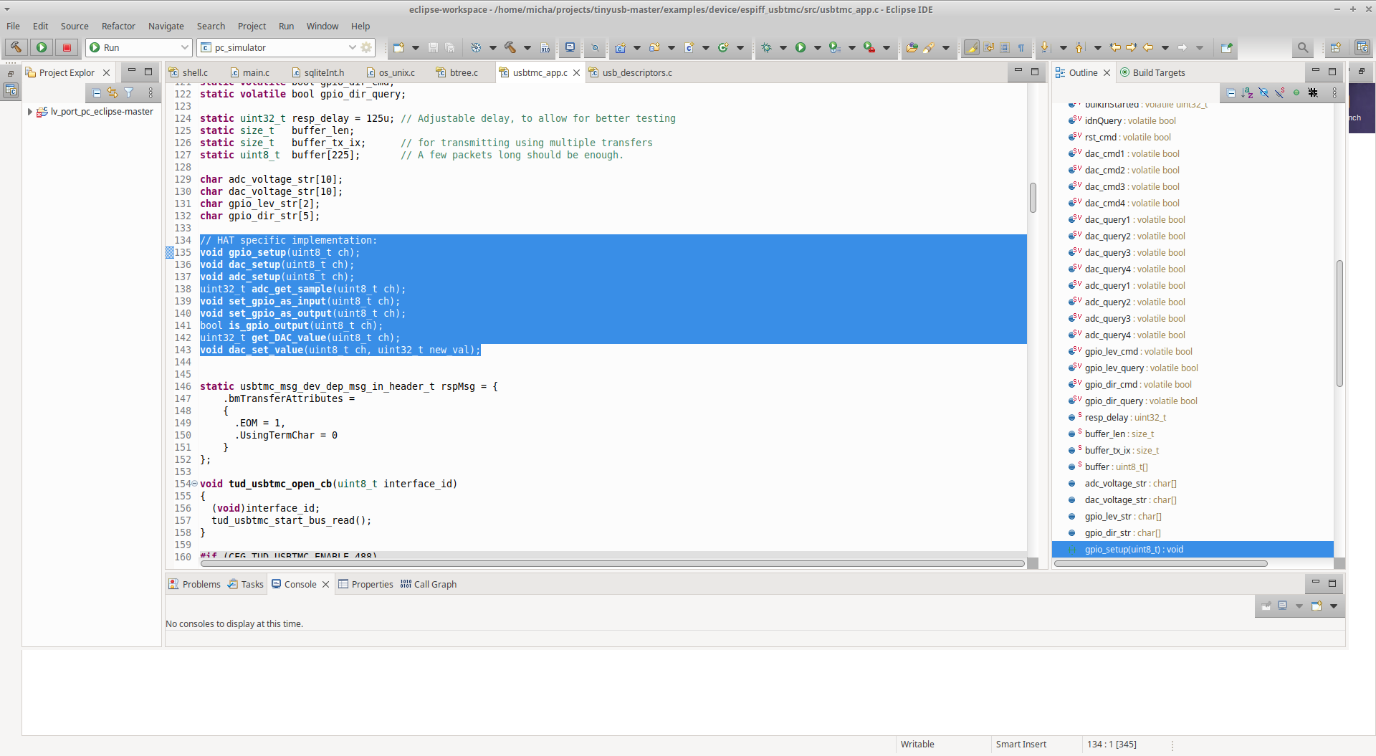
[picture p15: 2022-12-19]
images/usb_app_hat_specific_mod.png

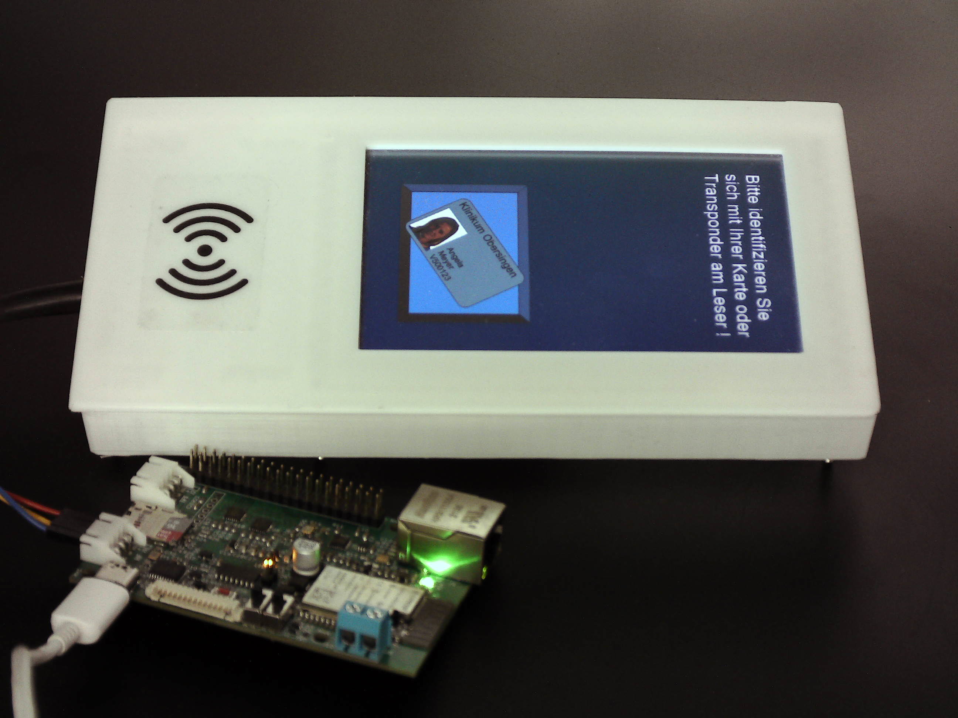
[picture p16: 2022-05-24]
images/espiff_HMI_vertical.jpg

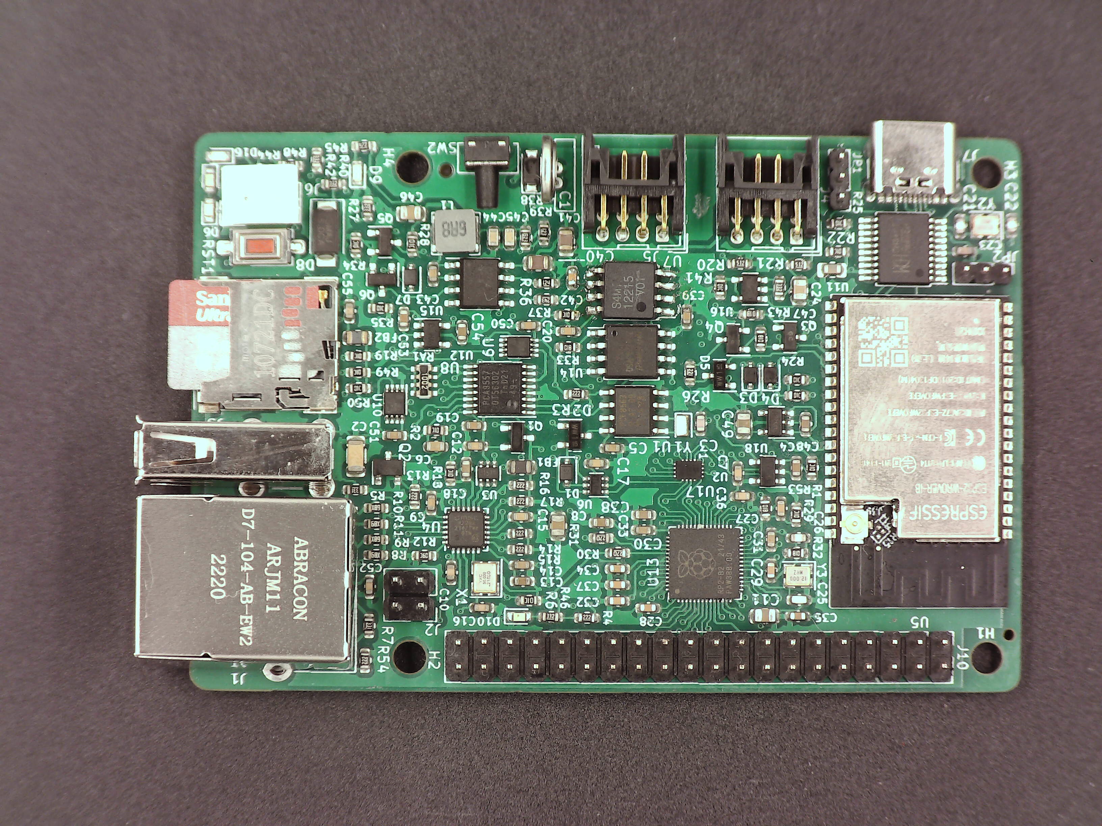
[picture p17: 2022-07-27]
images/espiff_v3_top1.jpg

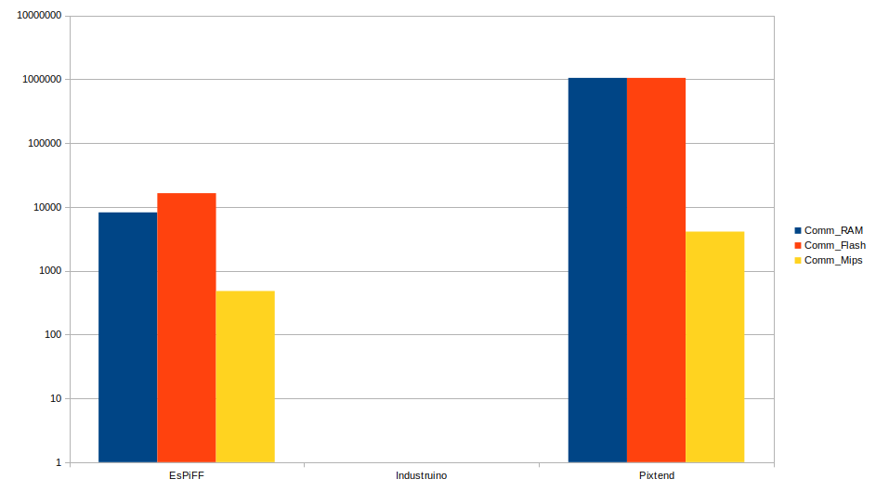
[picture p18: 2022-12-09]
images/EsPiFF_PLC_CommProc_compare.png

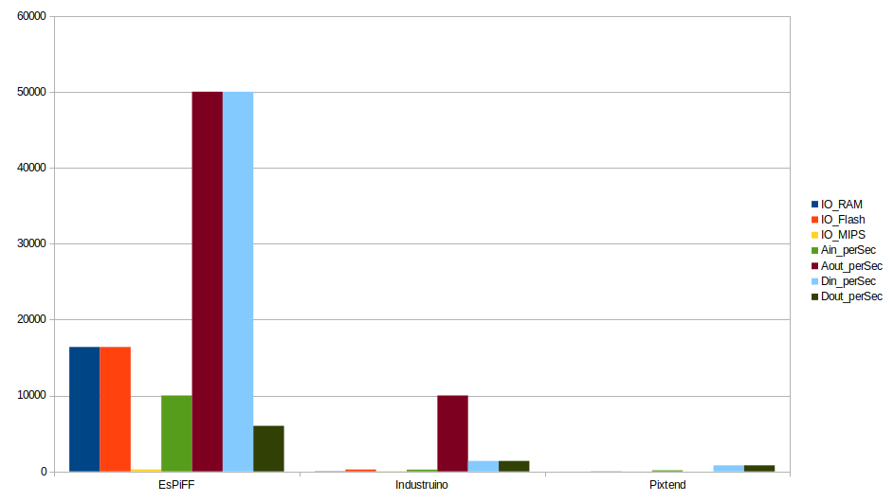
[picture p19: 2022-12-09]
images/EsPiFF_PLC_compare1.png

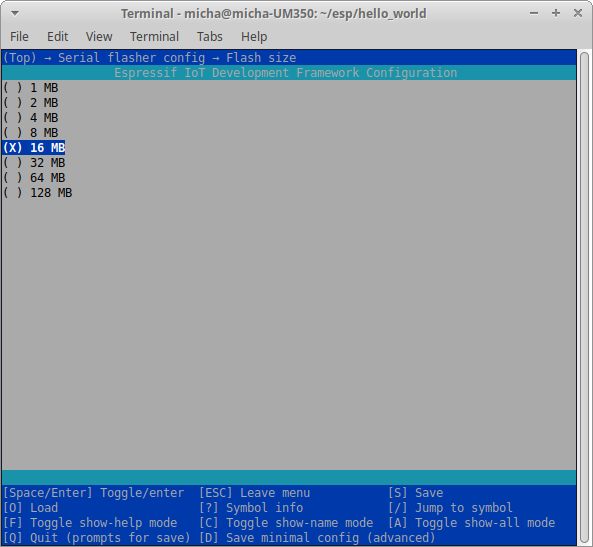
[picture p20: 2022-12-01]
images/cs_weekly/idf_hello_world5.png

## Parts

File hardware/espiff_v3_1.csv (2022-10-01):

Source: | /mnt/nfs/home/samba/projekte/espiff/pcb/version_3_fixed/espiff_v3_fixed.kicad_sch
Date: | Mi 07 Sep 2022 09:18:24 CEST
Tool: | Eeschema 6.0.7-f9a2dced07~116~ubuntu22.04.1
Generator: | /home/micha/kicad_libs/bom_csv_Schmid_JCLPCB.py
Component Count: | 172
Ref | Qnty | Value | MfgNo | Cmp name | Footprint | price@1 | price@reel | JCLPCB
C1, | 1 | 220mF/4V | DMS3R3224R | C_Polarized | mdc_footprints:supercap_DMS3R3224R | 0.41 | 0.27 | C113705
C2, | 1 | 1n/2kV | 1206B102K202NT | C_Small | Capacitor_SMD:C_1206_3216Metric | 0.006 | 0.005 | C9196
C3, | 1 | 22p | CL10C220JB8NNNC | C_Small | Capacitor_SMD:C_0603_1608Metric | 0.003 | 0.002 | C1653
C4, C9, C33, C38, C48, | 5 | 1u | CL10A105KB8NNNC | C_Small | Capacitor_SMD:C_0603_1608Metric | 0.006 | 0.004 | C15849
C5, C6, C7, C8, C12, C13, C16, C17, C18, C19, C20, C23, C27, C28, C29, C30, C31, C32, C34, C35, C36, C37, C39, C43, C50, C55, C56, | 27 | 100n | CC0603KRX7R9BB104 | C_Small | Capacitor_SMD:C_0603_1608Metric | 0.003 | 0.002 | C14663
C10, C24, C52, C57, | 4 | 22u/6.3V | CL10A226MQ8NRNC | C_Small | Capacitor_SMD:C_0805_2012Metric | 0.005 | 0.005 | C59461
C11, C46, C47, C49, | 4 | 47u/6.3V | CL21A476MQYNNNE | C_Small | Capacitor_SMD:C_0805_2012Metric | 0.03 | 0.02 | C16780
C14, C15, | 2 | 20p | CL10C200JB8NNNC | C_Small | Capacitor_SMD:C_0603_1608Metric | 0.007 | 0.006 | C1648
C21, C22, C25, C26, | 4 | 27p | CL10C270JB8NNNC | C_Small | Capacitor_SMD:C_0603_1608Metric | 0.003 | 0.002 | C1656
C40, C41, | 2 | 10u/50V | GRM21BR61H106KE43L | C_Small | Capacitor_SMD:C_0805_2012Metric | 0.10 | 0.07 | C440198
C42, | 1 | 2n7 | 0603B272K500NT | C_Small | Capacitor_SMD:C_0603_1608Metric | 0.003 | 0.002 | C1609
C44, C45, | 2 | 22u/10V | CL10A226MP8NUNE | C_Small | Capacitor_SMD:C_0603_1608Metric | 0.02 | 0.01 | C86295
C53, C54, | 2 | 10u/10V | CL10A106KP8NNNC | C_Small | Capacitor_SMD:C_0603_1608Metric | 0.007 | 0.005 | C19702
D1, D3, D4, | 3 | 1N5819WS | 1N5819WS | D_Small | Diode_SMD:D_SOD-323 | 0.02 | 0.02 | C191023
D2, D5, | 2 | BAT54C | BAT54C,215 | BAT54C | Package_TO_SOT_SMD:SOT-23 | 0.03 | 0.02 | C37704
D6, | 1 | LEDblue | 19-217/BHC-ZL1M2RY/3T | LED | LED_SMD:LED_0603_1608Metric | 0.03 | 0.02 | C72041
D7, | 1 | 1N5819 | 1N5819WS | D | Diode_SMD:D_SOD-323 | 0.02 | 0.02 | C191023
D8, | 1 | SMAJ6.0 | SMAJ6.0CA | D_Zener | Diode_SMD:D_SMA | 0.06 | 0.04 | C698928
D9, D13, | 2 | LEDyellow | 19-213/Y2C-CQ2R2L/3T(CY) | LED | LED_SMD:LED_0603_1608Metric | 0.04 | 0.02 | C72038
D10, | 1 | LEDgreen | 19-217/GHC-YR1S2/3T | LED | LED_SMD:LED_0603_1608Metric | 0.03 | 0.02 | C72043
D11, | 1 | SK4001 | SK4001 | D_Small | Diode_SMD:D_SOD-123 | 0.02 | 0.01 | C183406
D12, | 1 | LEDemerald | 19-217/GHC-YR1S2/3T | LED | LED_SMD:LED_0603_1608Metric | 0.02 | 0.01 | C72043
FB1, FB3, | 2 | FB0805 | UPZ2012E601-2R0TF | L_Ferrite | Resistor_SMD:R_0805_2012Metric | 0.02 | 0.01 | C98308
FB2, | 1 | FB_800mA | GZ2012D101TF | FerriteBead_Small | Resistor_SMD:R_0805_2012Metric | 0.01 | 0.01 | C1015
H1, H2, H3, H4, | 4 | MH | DNP | MountingHole | mdc_footprints:MountingHole_M3_3.2mm |  |  | DNP
J1, | 1 | HY931147C_PoE | HY931147C | HY931147C_PoE | mdc_footprints:HY931147C | 2.57 | 2.57 | C91754
J2, | 1 | ConPoE_2x2 | C66690 | Conn_02x02_Odd_Even | Connector_PinHeader_2.54mm:PinHeader_2x02_P2.54mm_Vertical | 0.03 | 0.02 | C66690
J3, | 1 | SDcard_molex | 5033981892 | SDcard_molex | molex_sdcard:MOLEX_503398-1892 | 0.59 | 0.38 | C428492
J4, J5, | 2 | ConDF11_2x4 | DF11-8DP-2DS(52) | Conn_02x04_Odd_Even | mdc_footprints:DF11-8DP-2DS(52) | 0.87 | 0.58 | C531042
J6, | 1 | Con_24Vin |  | Conn_01x02 | Connector_JST:JST_EH_B2B-EH-A_1x02_P2.50mm_Vertical
J7, | 1 | USB_C_Receptacle_USB2.0 | XKB_U262-16XN-4BVC11 | USB_C_Receptacle_USB2.0 | mdc_footprints:USB_C_XKB_U262-16XN-4BVC11 | 0.35 | 0.21 | C319148
J8, | 1 | HMI_ESP32c3_hostSide | SM06B-SURS-TF(LF)(SN) | HMI_ESP32c3_hostSide | Connector_JST:JST_SUR_SM06B-SURS-TF_1x06-1MP_P0.80mm_Horizontal | 0.32 | 0.18 | C495545
J9, | 1 | USB_A | C26235 | USB_A | mdc_footprints:USB_A_C26235 | 0.2 | 0.14 | C26235
J10, | 1 | Raspberry_Pi_2_3 | B-2100S40P-B110 | Raspberry_Pi_2_3 | Connector_PinHeader_2.54mm:PinHeader_2x20_P2.54mm_Vertical | 0.27 | 0.19 | C124383
JP1, | 1 | JP_HF_USB_MOSI | PZ200V-11-03P | Jumper_3_Bridged12 | Connector_PinHeader_2.00mm:PinHeader_1x03_P2.00mm_Vertical | 0.02 | 0.01 | C541857
JP2, | 1 | JP_WTI | DNP | Jumper_2_Open | Jumper:SolderJumper-2_P1.3mm_Open_Pad1.0x1.5mm |  |  | DNP
JP3, | 1 | JP_ResetSel |  | SolderJumper_3_Bridged12 | Jumper:SolderJumper-3_P1.3mm_Bridged12_RoundedPad1.0x1.5mm
JP4, | 1 | JP_HF_USB_MISO | PZ200V-11-03P | Jumper_3_Bridged12 | Connector_PinHeader_2.00mm:PinHeader_1x03_P2.00mm_Vertical | 0.02 | 0.01 | C541857
L1, | 1 | 6uH8 | MWSA0402S-6R8MT | L | Inductor_SMD:L_Bourns-SRN4018 | 0.16 | 0.11 | C408338
Q3, Q4, | 2 | BC817 | BC817-40 | Q_NPN_BEC | Package_TO_SOT_SMD:SOT-23 | 0.03 | 0.02 | C8589
Q5, Q6, | 2 | 2N7002 | 2N7002 | 2N7002 | Package_TO_SOT_SMD:SOT-23 | 0.03 | 0.02 | C8545
R1, R17, R18, R19, R22, R25, R28, R29, R34, R35, R41, R47, R48, R49, R50, R51, R52, | 17 | 10k | 0603WAF1002T5E | R | Resistor_SMD:R_0603_1608Metric | 0.003 | 0.002 | C25804
R2, R8, R23, R24, R32, R33, R53, | 7 | 1k | 0603WAF1001T5E | R | Resistor_SMD:R_0603_1608Metric | 0.003 | 0.002 | C21190
R3, R4, | 2 | 2.2k | 0603WAF2201T5E | R | Resistor_SMD:R_0603_1608Metric | 0.003 | 0.002 | C4190
R5, R7, R10, R12, R14, R15, R16, R20, R21, | 9 | 5k1 | 0603WAF5101T5E | R | Resistor_SMD:R_0603_1608Metric | 0.003 | 0.002 | C23186
R6, R9, R30, R31, | 4 | 27R | 0603WAF270JT5E | R | Resistor_SMD:R_0603_1608Metric | 0.003 | 0.002 | C25190
R11, | 1 | 0R | 0603WAF0000T5E | R | Resistor_SMD:R_0603_1608Metric | 0.003 | 0.002 | C21189
R13, | 1 | 6k19 | 0603WAF6191T5E | R | Resistor_SMD:R_0603_1608Metric | 0.003 | 0.002 | C25978
R26, | 1 | 220R | 0603WAF2200T5E | R | Resistor_SMD:R_0603_1608Metric | 0.003 | 0.002 | C22962
R27, R40, R42, R43, R44, R46, | 6 | 3k3 | 0603WAF3301T5E | R | Resistor_SMD:R_0603_1608Metric | 0.003 | 0.002 | C22978
R36, | 1 | 120k | 0603WAF1203T5E | R | Resistor_SMD:R_0603_1608Metric | 0.003 | 0.002 | C25808
R37, | 1 | 24k | 0603WAF2402T5E | R | Resistor_SMD:R_0603_1608Metric | 0.003 | 0.002 | C23352
R38, | 1 | 62k | 0603WAF6202T5E | R | Resistor_SMD:R_0603_1608Metric | 0.003 | 0.002 | C23221
R39, | 1 | 12k | 0603WAF1202T5E | R | Resistor_SMD:R_0603_1608Metric | 0.003 | 0.002 | C22790
R45, | 1 | 4k7 | 0603WAF4701T5E | R | Resistor_SMD:R_0603_1608Metric | 0.003 | 0.002 | C23162
RA1, | 1 | 10k | 4D03WGF1002T5(E) | R_array_4x_4D03 | Resistor_SMD:R_Array_Convex_4x0603 | 0.02 | 0.008 | C109324
RST1, | 1 | Reset | UK-B0240-R-250-JZ | SW_Push | mdc_footprints:Btn_KEY-SMD_JCLPCB_C698192 | 0.06 | 0.04 | C698192
SW2, | 1 | USB_BOOT | TC-1109DE-C-H | SW_PUSH_GND | mdc_footprints:Btn_TC-1109DE-C-F | 0.04 | 0.03 | C400335
U1, | 1 | PCF8563T | PCF8563T/5,518 | PCF8563T | Package_SO:SOIC-8_3.9x4.9mm_P1.27mm | 0.94 | 0.64 | C7440
U2, | 1 | APX823 | APX823-26W5G-7 | APX823 | Package_TO_SOT_SMD:SOT-23-5 | 0.25 | 0.16 | C156283
U3, U6, | 2 | 741G3157 | SGM3157 | 741G3157 | Package_TO_SOT_SMD:SOT-363_SC-70-6 | 0.08 | 0.06 | C394901
U4, | 1 | IP101GR | IP101GRI | IP101GR | Package_DFN_QFN:QFN-32-1EP_4x4mm_P0.4mm_EP2.65x2.65mm | 1.86 | 1.32 | C910373
U5, | 1 | ESP32-WROVER-E | ESP32-WROVER-IB(16MB) | ESP32-WROVER-E | Espressif:ESP32-WROVER-E | 5.21 | 4.04 | C529592
U7, | 1 | PCA9557PW | PCA9557PW,118 | PCA9557PW | Package_SO:TSSOP-16_4.4x5mm_P0.65mm | 0.65 | 0.48 | C141380
U8, | 1 | FM25CL64B | FM25CL64B-GTR | MX25R3235FM2xx1 | mdc_footprints:SOIC8_W+N_combi | 3.26 | 2.23 | C9830
U9, | 1 | 74xx2G32 | SN74LVC2G32DCUR | 74xx2G32 | Package_SO:VSSOP-8_2.3x2mm_P0.5mm | 0.27 | 0.2 | C91874
U11, | 1 | CH340T | CH340T | CH340T | Package_SO:SSOP-20_5.3x7.2mm_P0.65mm | 0.66 | 0.41 | C8689
U12, U16, | 2 | MT9700 | MT9700 | MT9700_2 | Package_TO_SOT_SMD:SOT-23-5 | 0.11 | 0.07 | C89855
U13, | 1 | RP2040_alternateFuncs | RP2040 | RP2040_alternateFuncs | mdc_footprints:QFN56_ThermalVias_0.3 | 1.35 | 0.95 | C2040
U14, | 1 | W25Q128 | W25Q128JVSIQ | W25Q32JVSS | mdc_footprints:SOIC8_5.23x5.23mm_P1.27mm_mdc | 1.05 | 0.72 | C97521
U15, | 1 | RT7272 | RT7272BGSP | RT7272 | mdc_footprints:SOIC8-1EP_3.9x4.9mm_P1.27_ThermalVias | 0.65 | 0.43 | C127866
U17, | 1 | TS3A5018 | TS3A5018RSVR | TS3A5018PW | mdc_footprints:UQFN-16_1.8x2.6_P0.4mm | 0.84 | 0.60 | C201641
U18, | 1 | ME6211 | ME6211C33M5G-N | ME6211 | Package_TO_SOT_SMD:SOT-23-5 | 0.07 | 0.05 | C82942
Y1, | 1 | 32kHz | TJXM32768K2TGDCNT2T | Crystal | Crystal:Crystal_SMD_2012-2Pin_2.0x1.2mm | 0.29 | 0.21 | C403709
Y2, Y3, | 2 | 12MHz | S22120001210120 | Crystal_GND24 | Crystal:Crystal_SMD_2520-4Pin_2.5x2.0mm | 0.14 | 0.09 | C479184
Y4, | 1 | 25MHz | X322525MOB4SI | Crystal_GND24 | Crystal:Crystal_SMD_3225-4Pin_3.2x2.5mm | 0.08 | 0.05 | C9006

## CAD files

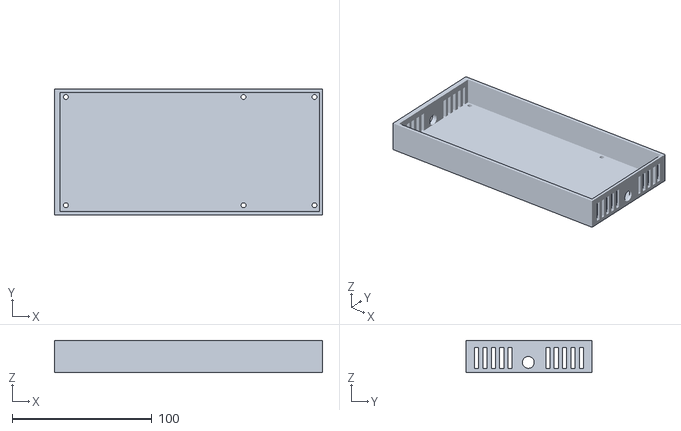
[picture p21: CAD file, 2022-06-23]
examples/enclosure_3Dprintable/enclosure_3Dprinter_cap.stl
192.0 x 90.0 x 23.0

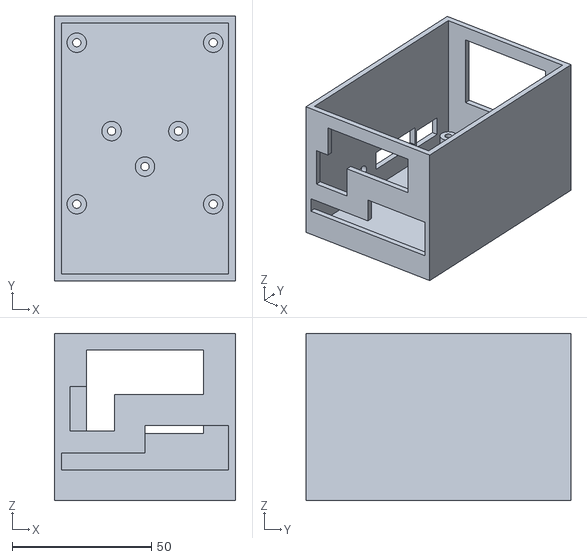
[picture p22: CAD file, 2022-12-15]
HATs/ESPiFF-PLC-2.stl
65.0 x 95.0 x 60.0

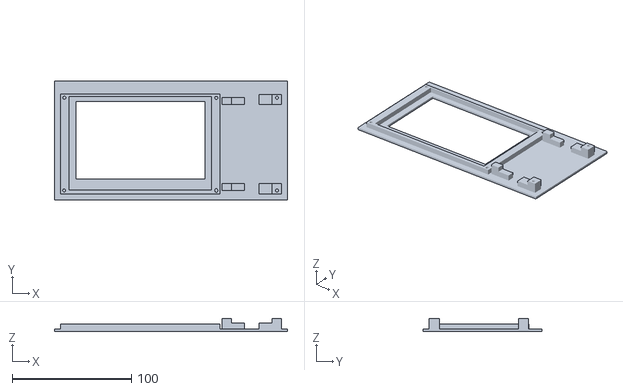
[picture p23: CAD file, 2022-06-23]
examples/enclosure_3Dprintable/enclosure_3Dprinter.stl
195.0 x 100.0 x 11.0

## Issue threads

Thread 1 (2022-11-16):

Please clarify how the ESP32 and RP2040 communicate

jasongaunt, 2022-11-16:
Hi MDC,

I really like the potential of this product, however it's not clear in the documentation (README) how the ESP32 and RP2040 will communicate with each other.

Ideally, there should be:

- A fast and low latency bus like SPI or I2C between them
- A way for the ESP32 to program the RP2040 (so OTA can be performed on both)

Kind regards,
Jason

jasongaunt, 2022-11-19:
@MDCservice Much appreciated for the extra information, can't wait for these to be released.

I plan on using one to directly drive LCD panels with the RP2040 acting as a graphics accelerator, the aim being to be able to draw a full car dash cluster in real time 😄

Marking this issue as resolved!

Closed 2022-11-19.

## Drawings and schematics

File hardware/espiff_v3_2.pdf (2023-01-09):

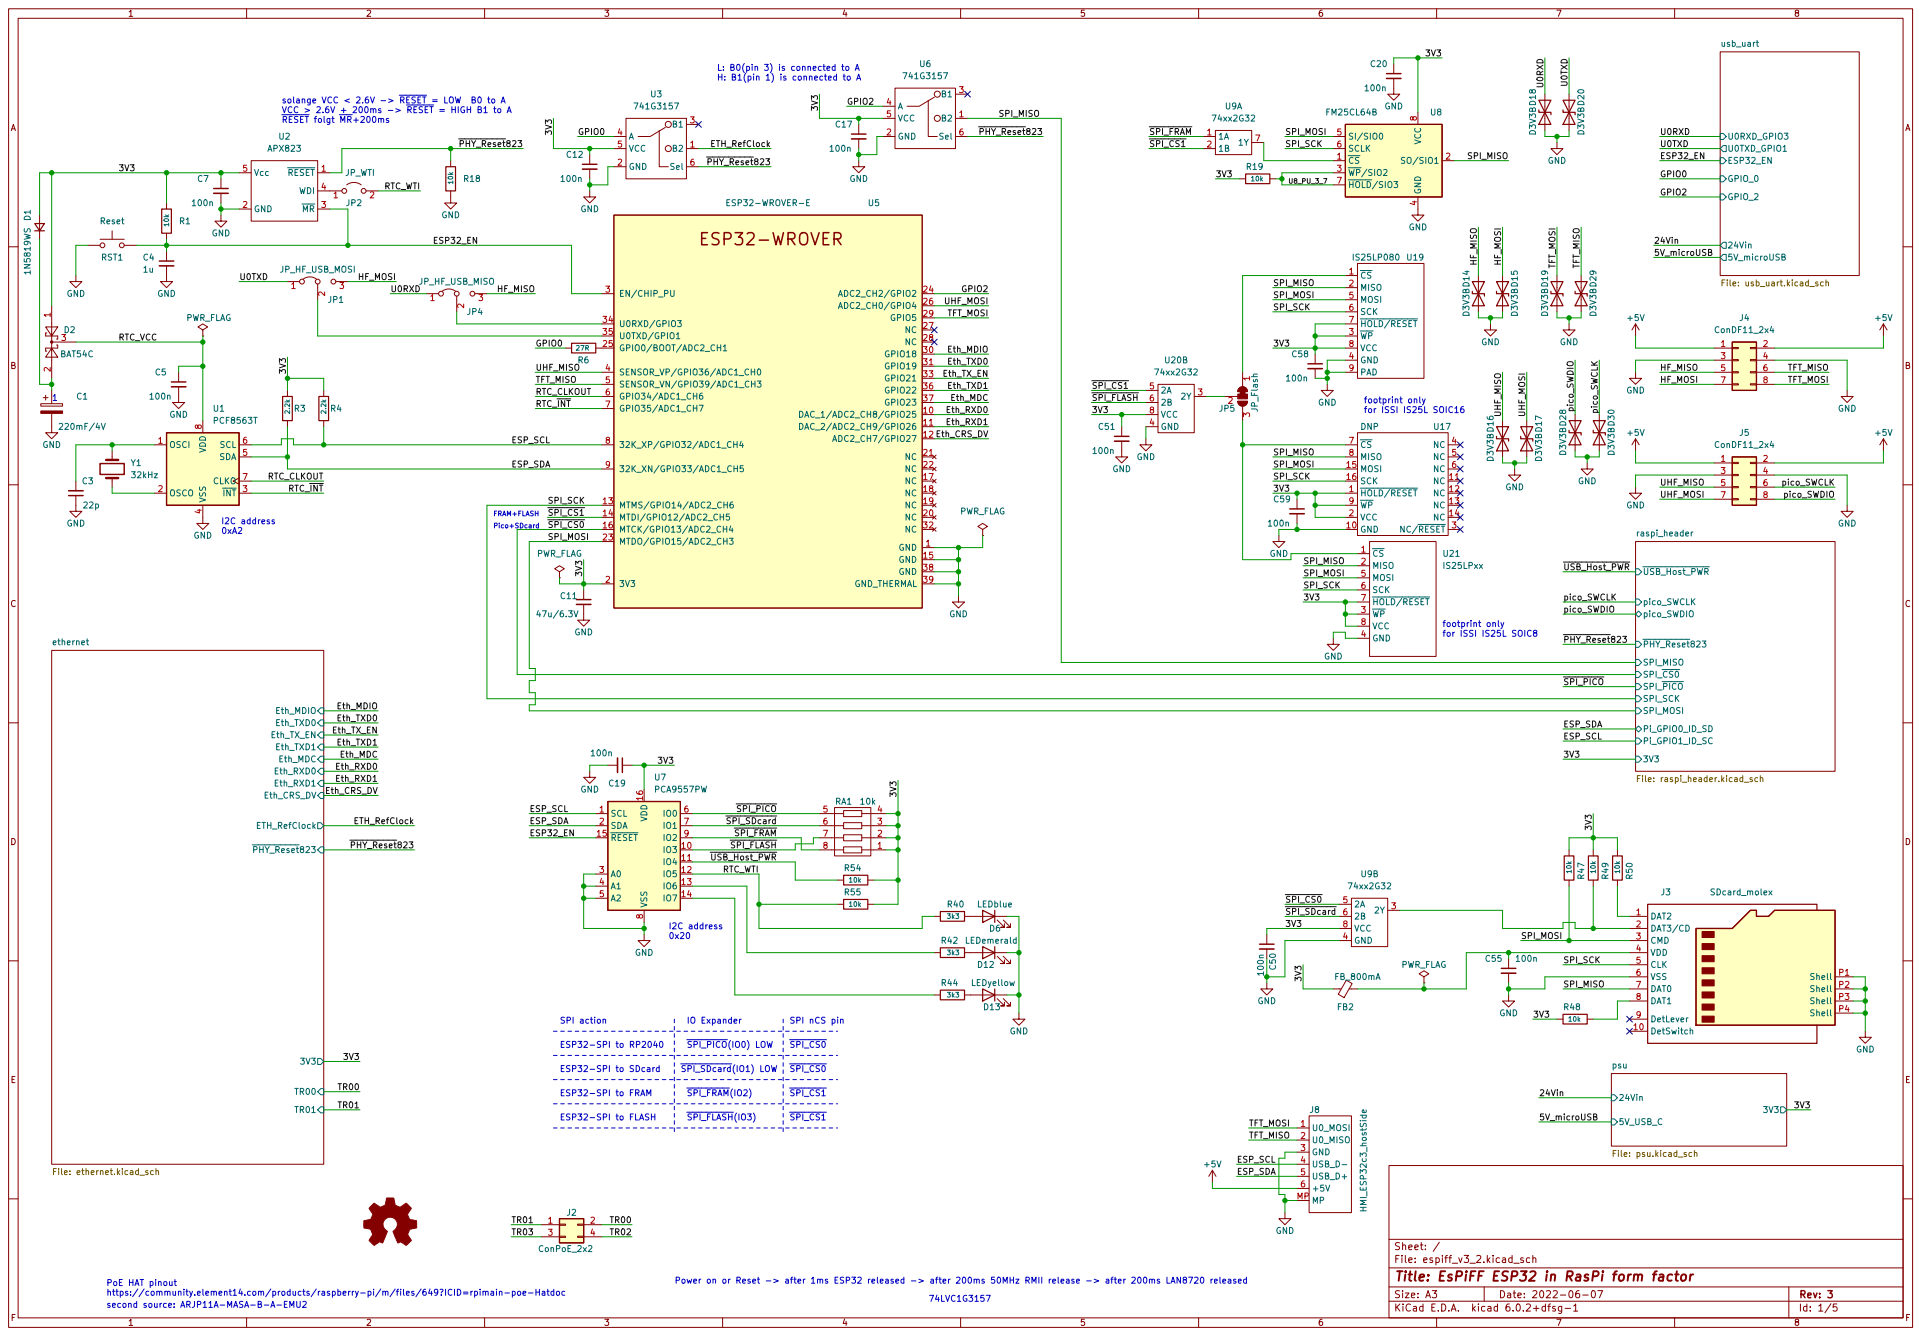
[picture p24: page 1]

L: B0(pin 3) is connected to A
H: B1(pin 1) is connected to A

solange VCC < 2.6V -> ~{RESET} = LOW B0 to A
VCC > 2.6V + 200ms -> ~{RESET} = HIGH B1 to A
~{RESET} folgt ~{MR}+200ms

4 SI/SIO0 5 SCLK 6 ~{HOLD}/SIO3 7 VCC

4 SDA 5 SCL 6 CLKO 7 VDD

I2C address 0x20 PoE HAT pinout

IO Expander ESP32-SPI to FLASH

File: espiff_v3_2.kicad_sch Sheet: /
Id: 1/5 Title: EsPiFF ESP32 in RasPi form factor

https://community.element14.com/products/raspberry-pi/m/files/649?ICID=rpimain-poe-Hatdoc

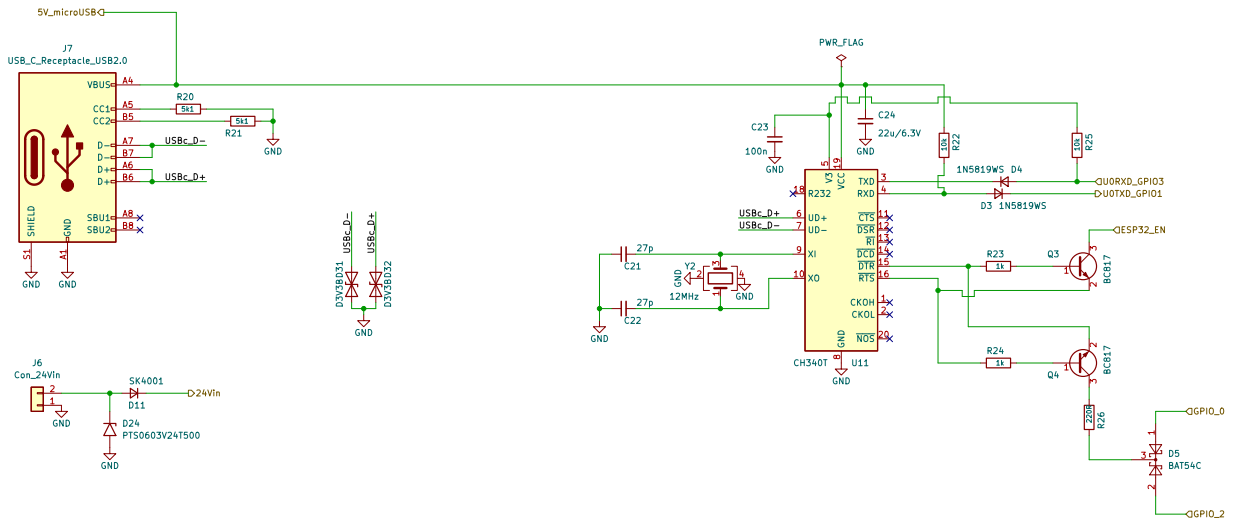
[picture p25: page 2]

Sheet: /usb_uart/
File: usb_uart.kicad_sch
Id: 2/5 Title: USB to UART bridge

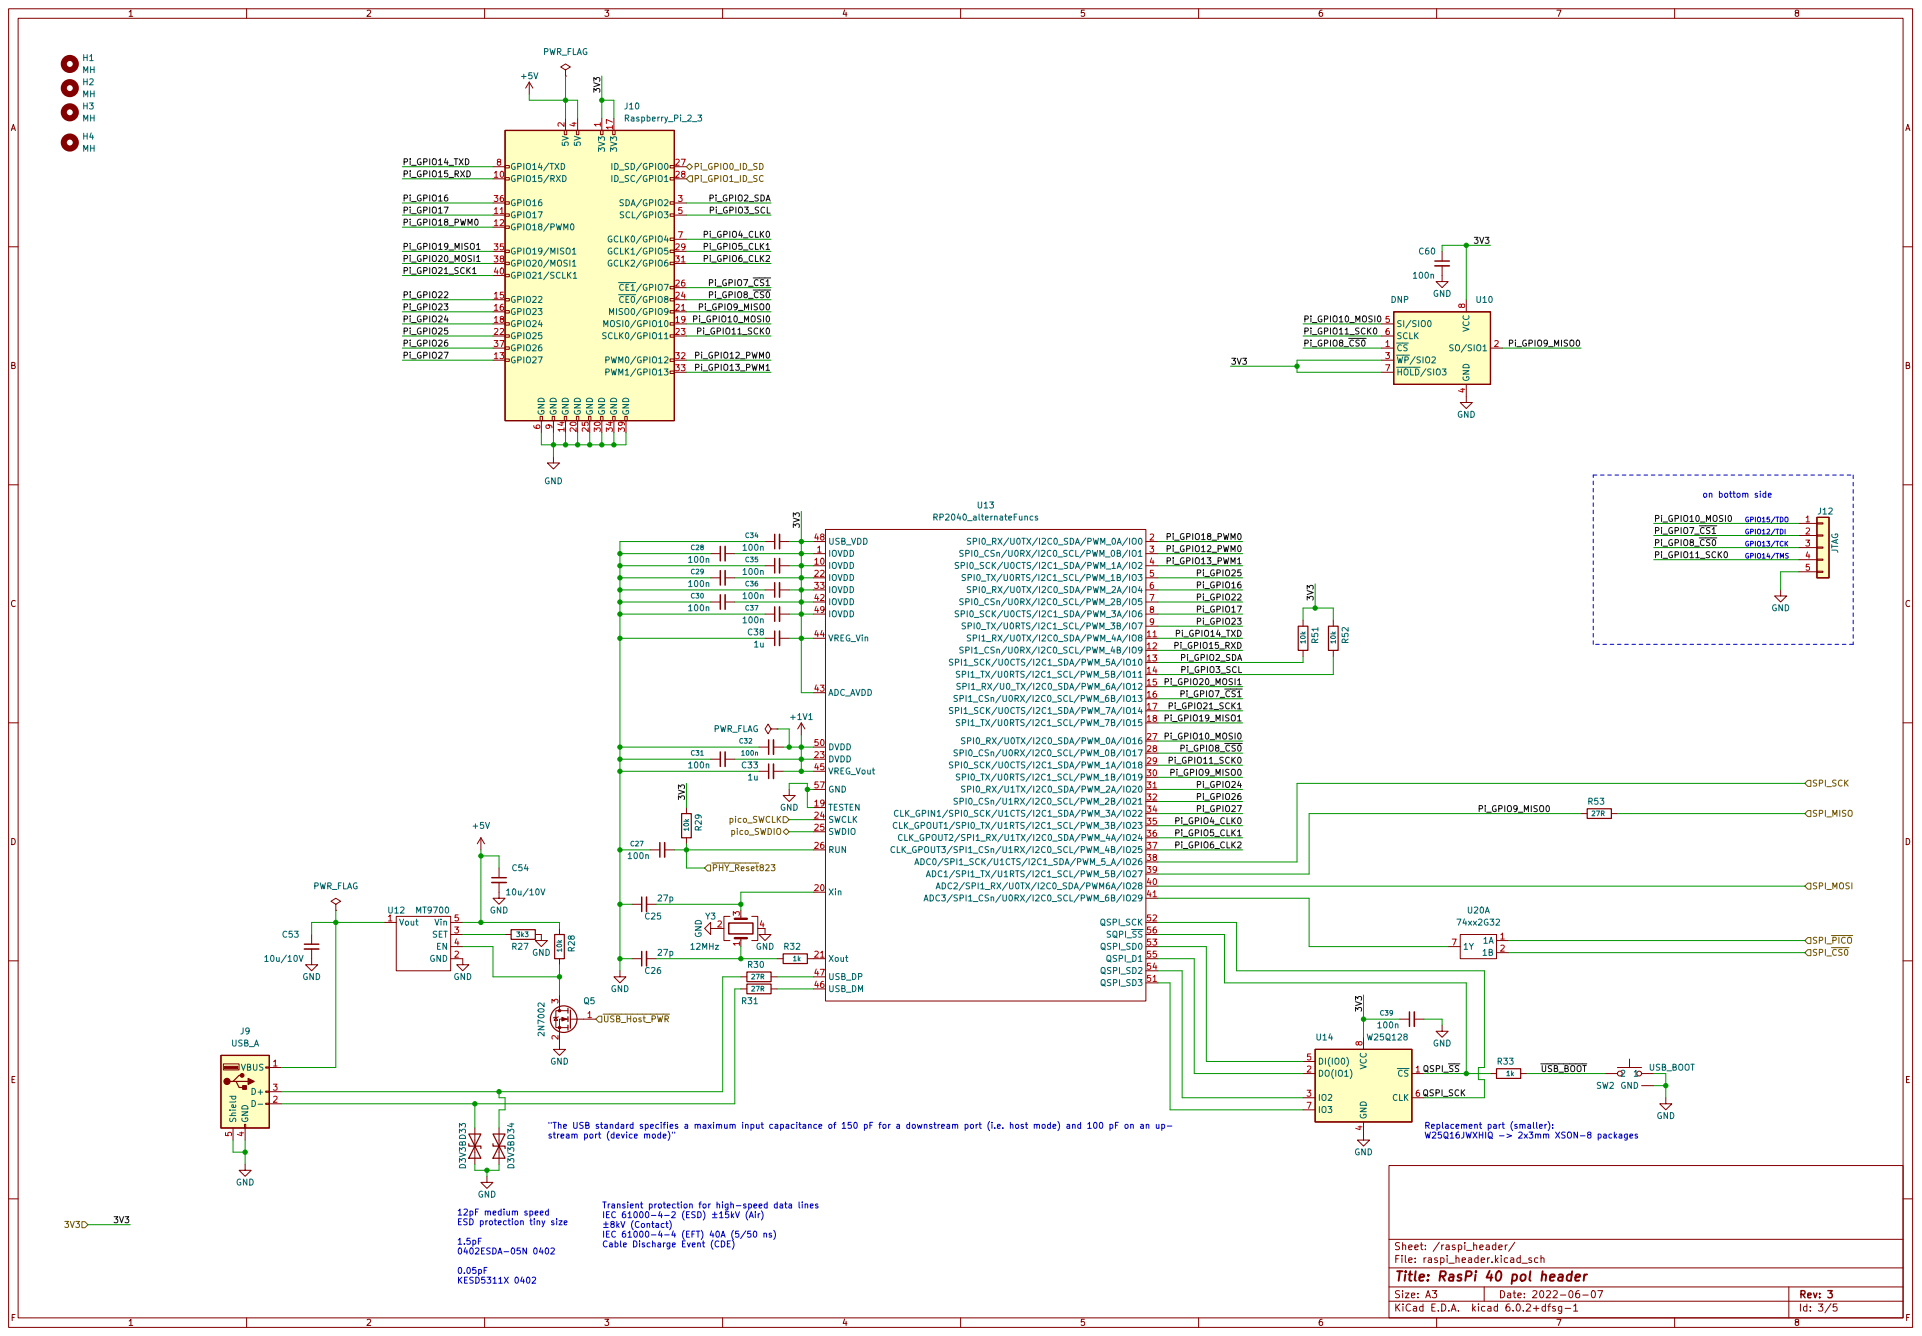
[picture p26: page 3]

4 SI/SIO0 5 SCLK 6 ~{HOLD}/SIO3 7 VCC

GPIO13/TCK on bottom side GPIO15/TDO

"The USB standard specifies a maximum input capacitance of 150 pF for a downstream port (i.e. host mode) and 100 pF on an up-
stream port (device mode)"

Transient protection for high-speed data lines
IEC 61000-4-4 (EFT) 40A (5/50 ns)
Cable Discharge Event (CDE)

12pF medium speed
ESD protection tiny size

File: raspi_header.kicad_sch
Id: 3/5 Title: RasPi 40 pol header

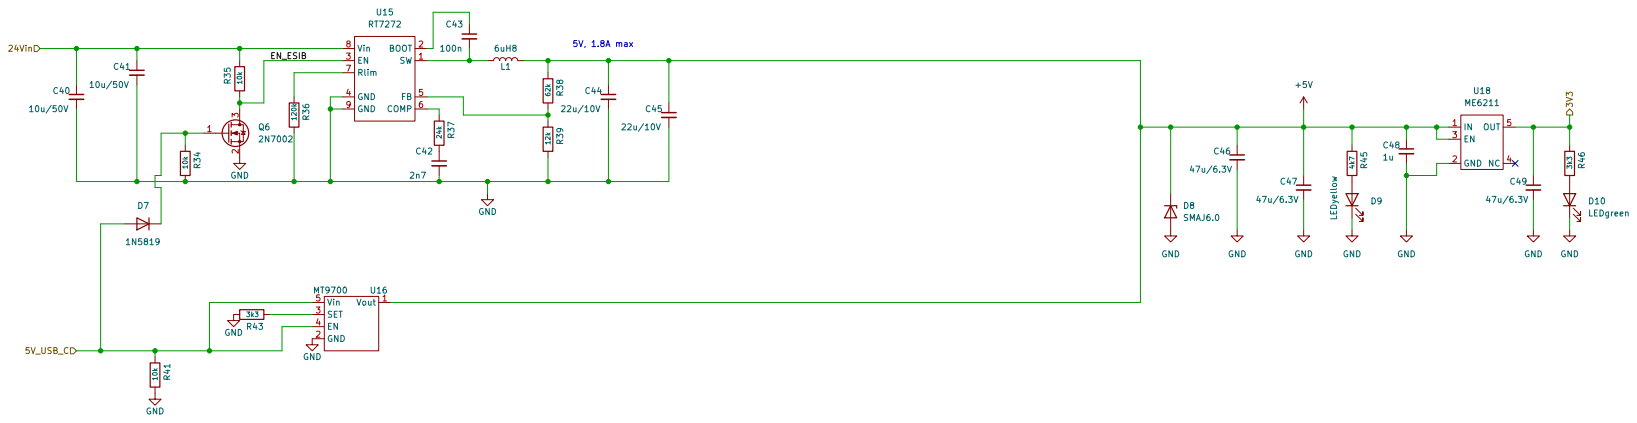
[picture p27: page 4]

Sheet: /psu/
File: psu.kicad_sch
Id: 4/5 Title: Power supply

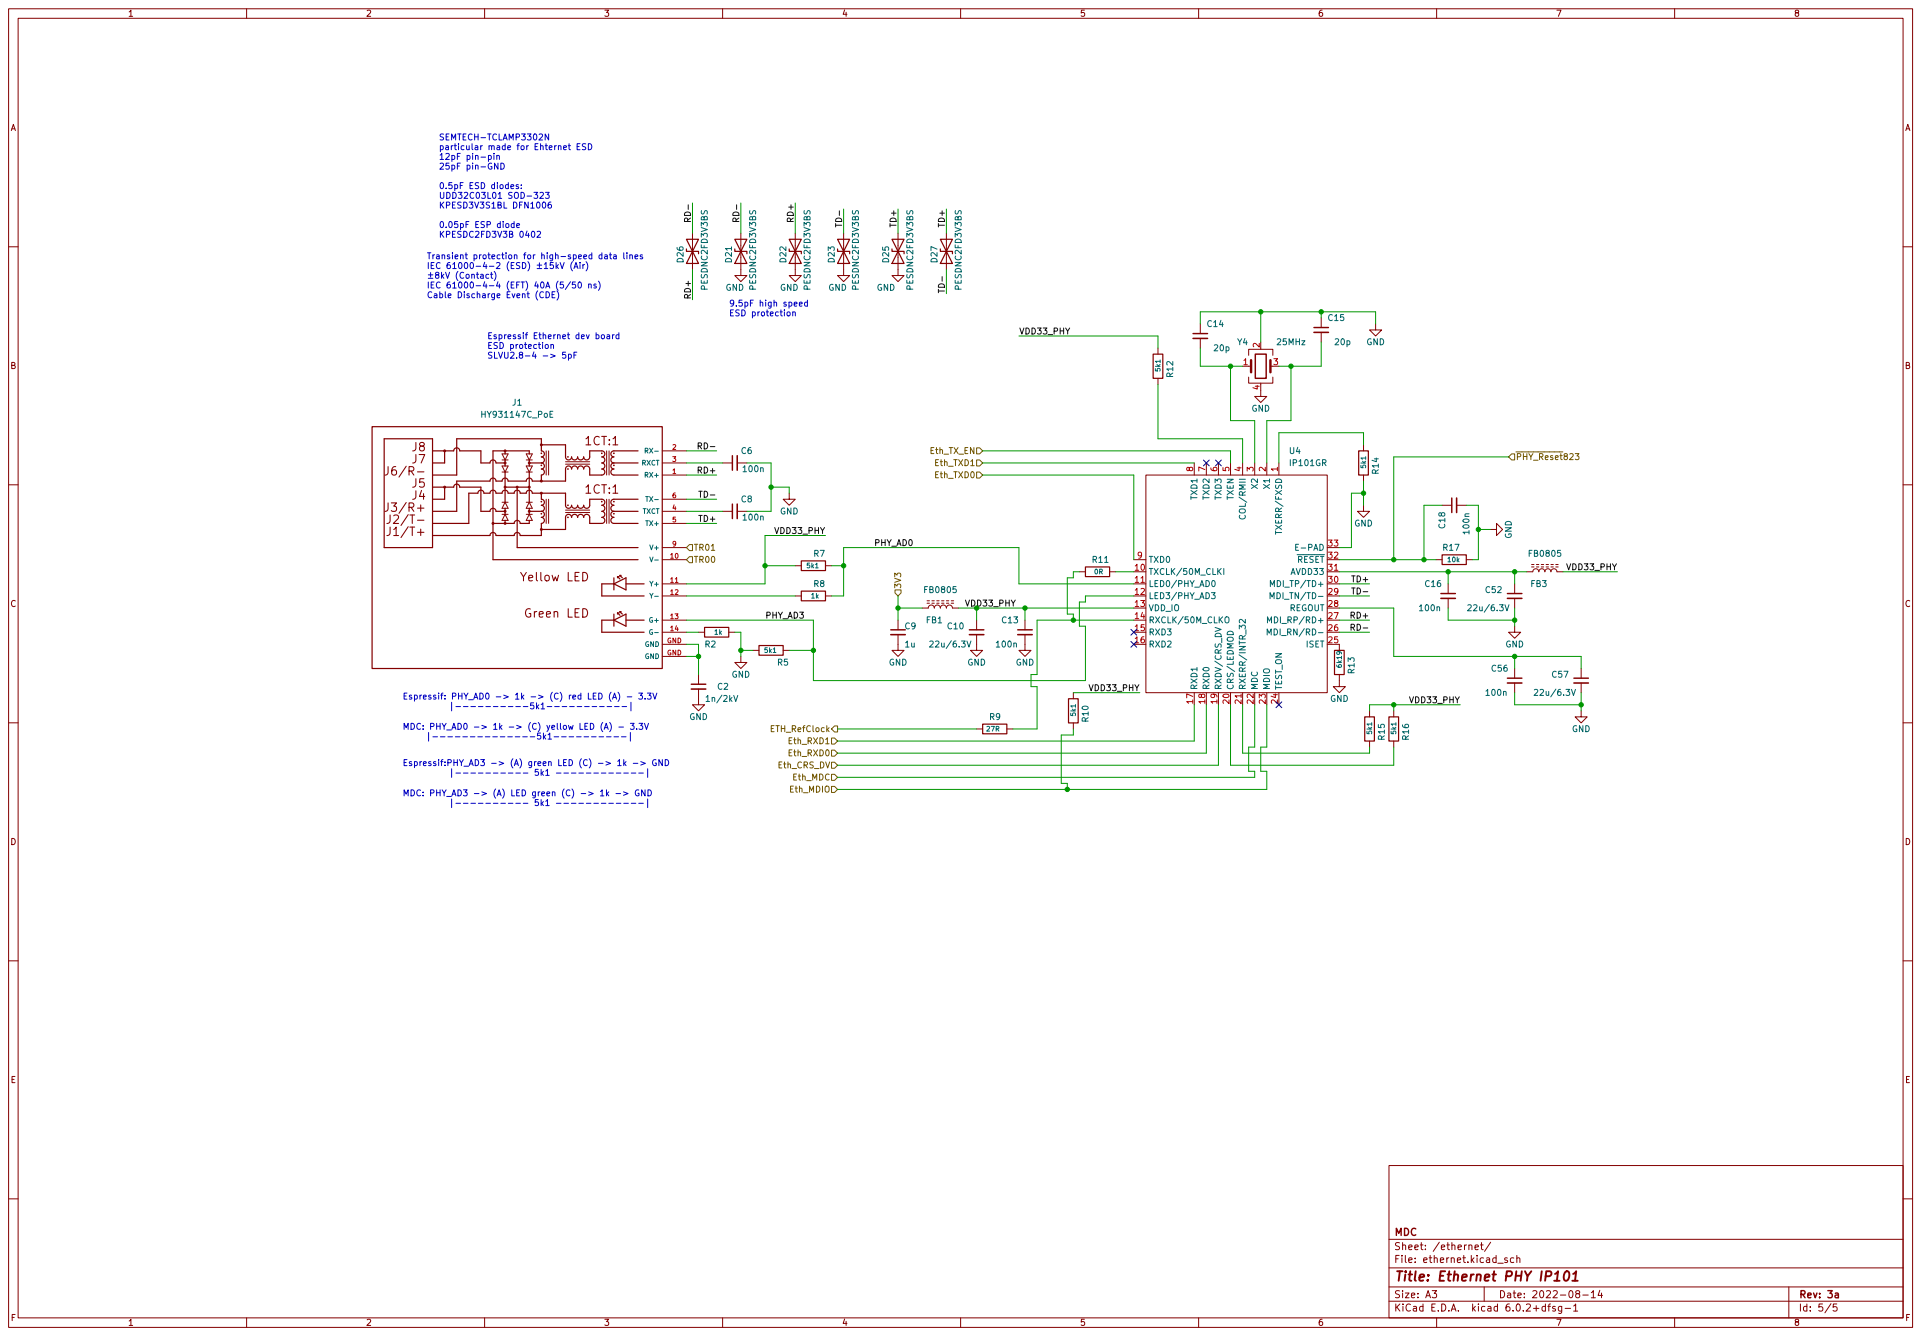
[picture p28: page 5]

0.05pF ESP diode KPESDC2FD3V3B 0402 MDC: PHY_AD3 -> (A) LED green (C) -> 1k -> GND
9.5pF high speed
ESD protection

SLVU2.8-4 -> 5pF SEMTECH-TCLAMP3302N
particular made for Ehternet ESD
12pF pin-pin
25pF pin-GND

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

Espressif Ethernet dev board

2 CRS/LEDMOD 20 RXERR/INTR_32 21 MDC 22 MDIO 23 TEST_ON 24

3 MDI_TP/TD+ 30 AVDD33 31 ~{RESET}32 E-PAD 33 COL/RMII 4 TXEN

Espressif:PHY_AD3 -> (A) green LED (C) -> 1k -> GND

File: ethernet.kicad_sch Sheet: /ethernet/ MDC

Id: 5/5 Title: Ethernet PHY IP101

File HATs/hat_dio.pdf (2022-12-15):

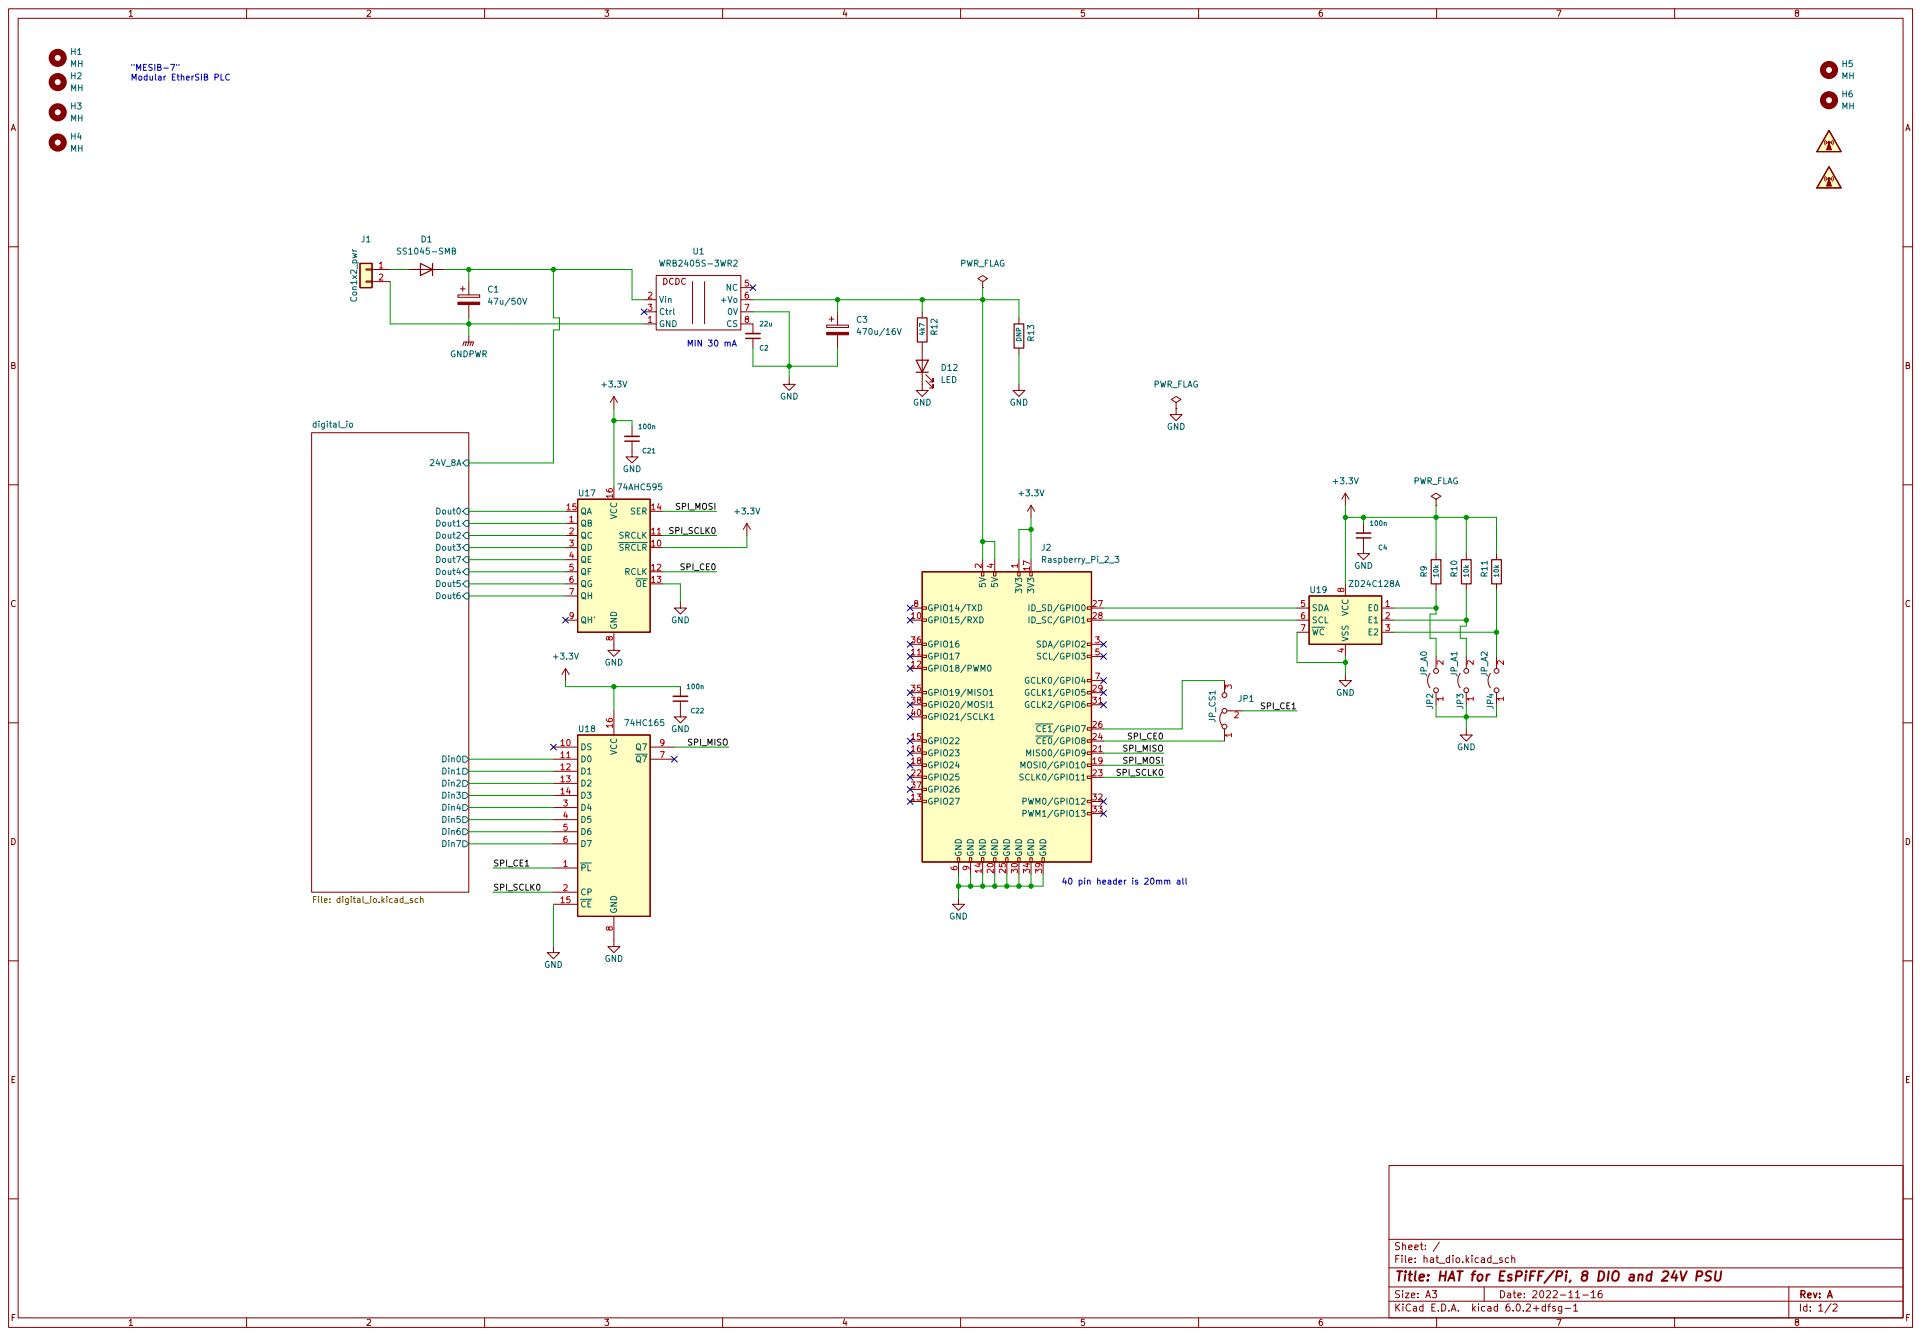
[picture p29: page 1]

"MESIB-7" Modular EtherSIB PLC

4 SDA 5 SCL 6 ~{WC} 7 VCC

40 pin header is 20mm all

Id: 1/2 Title: HAT for EsPiFF/Pi, 8 DIO and 24V PSU

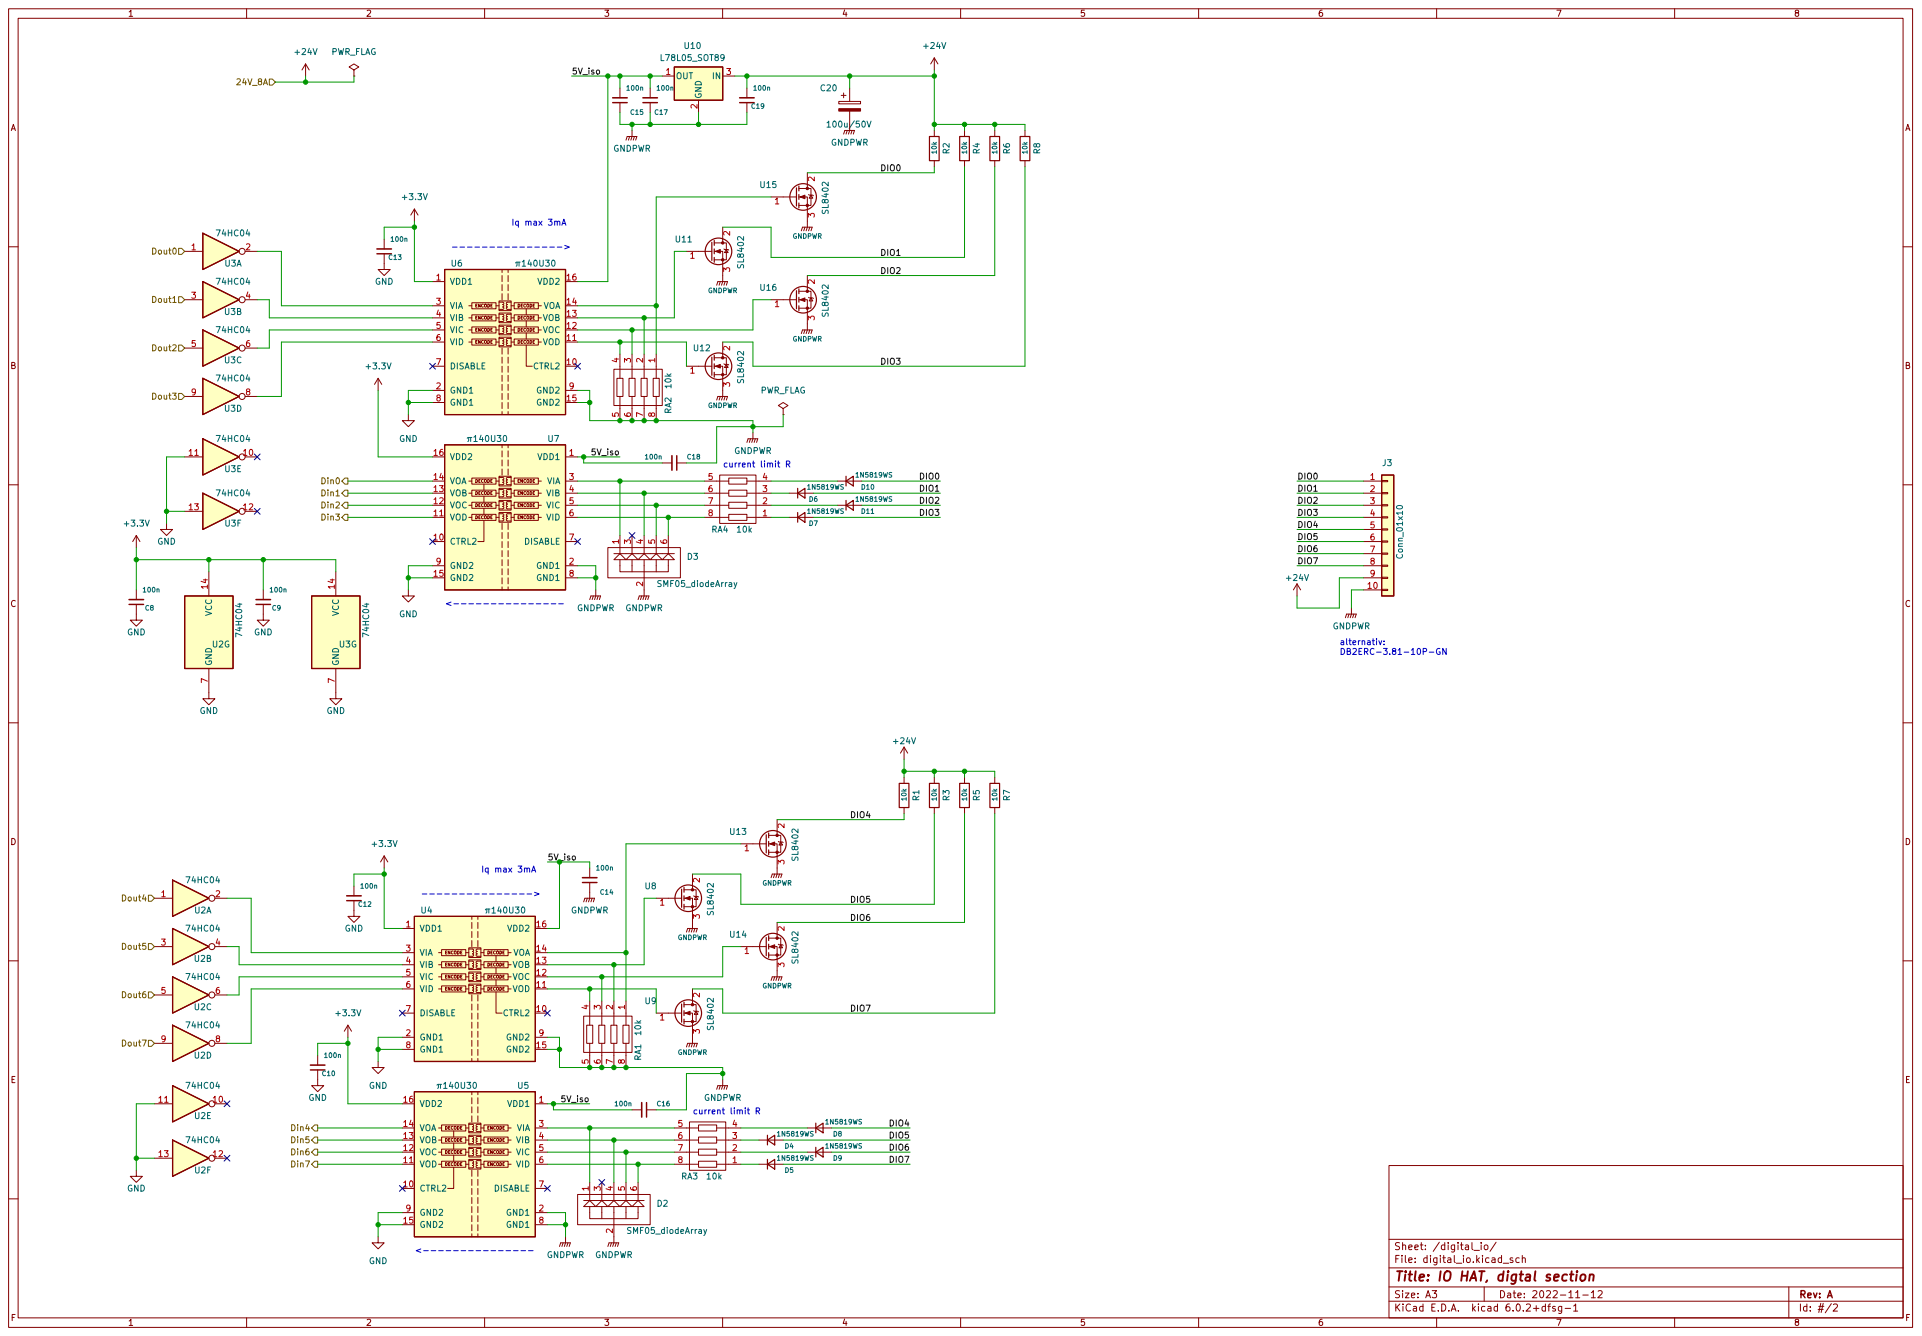
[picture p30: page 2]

DECODE DECODE

File: digital_io.kicad_sch
Id: #/2 Title: IO HAT, digtal section

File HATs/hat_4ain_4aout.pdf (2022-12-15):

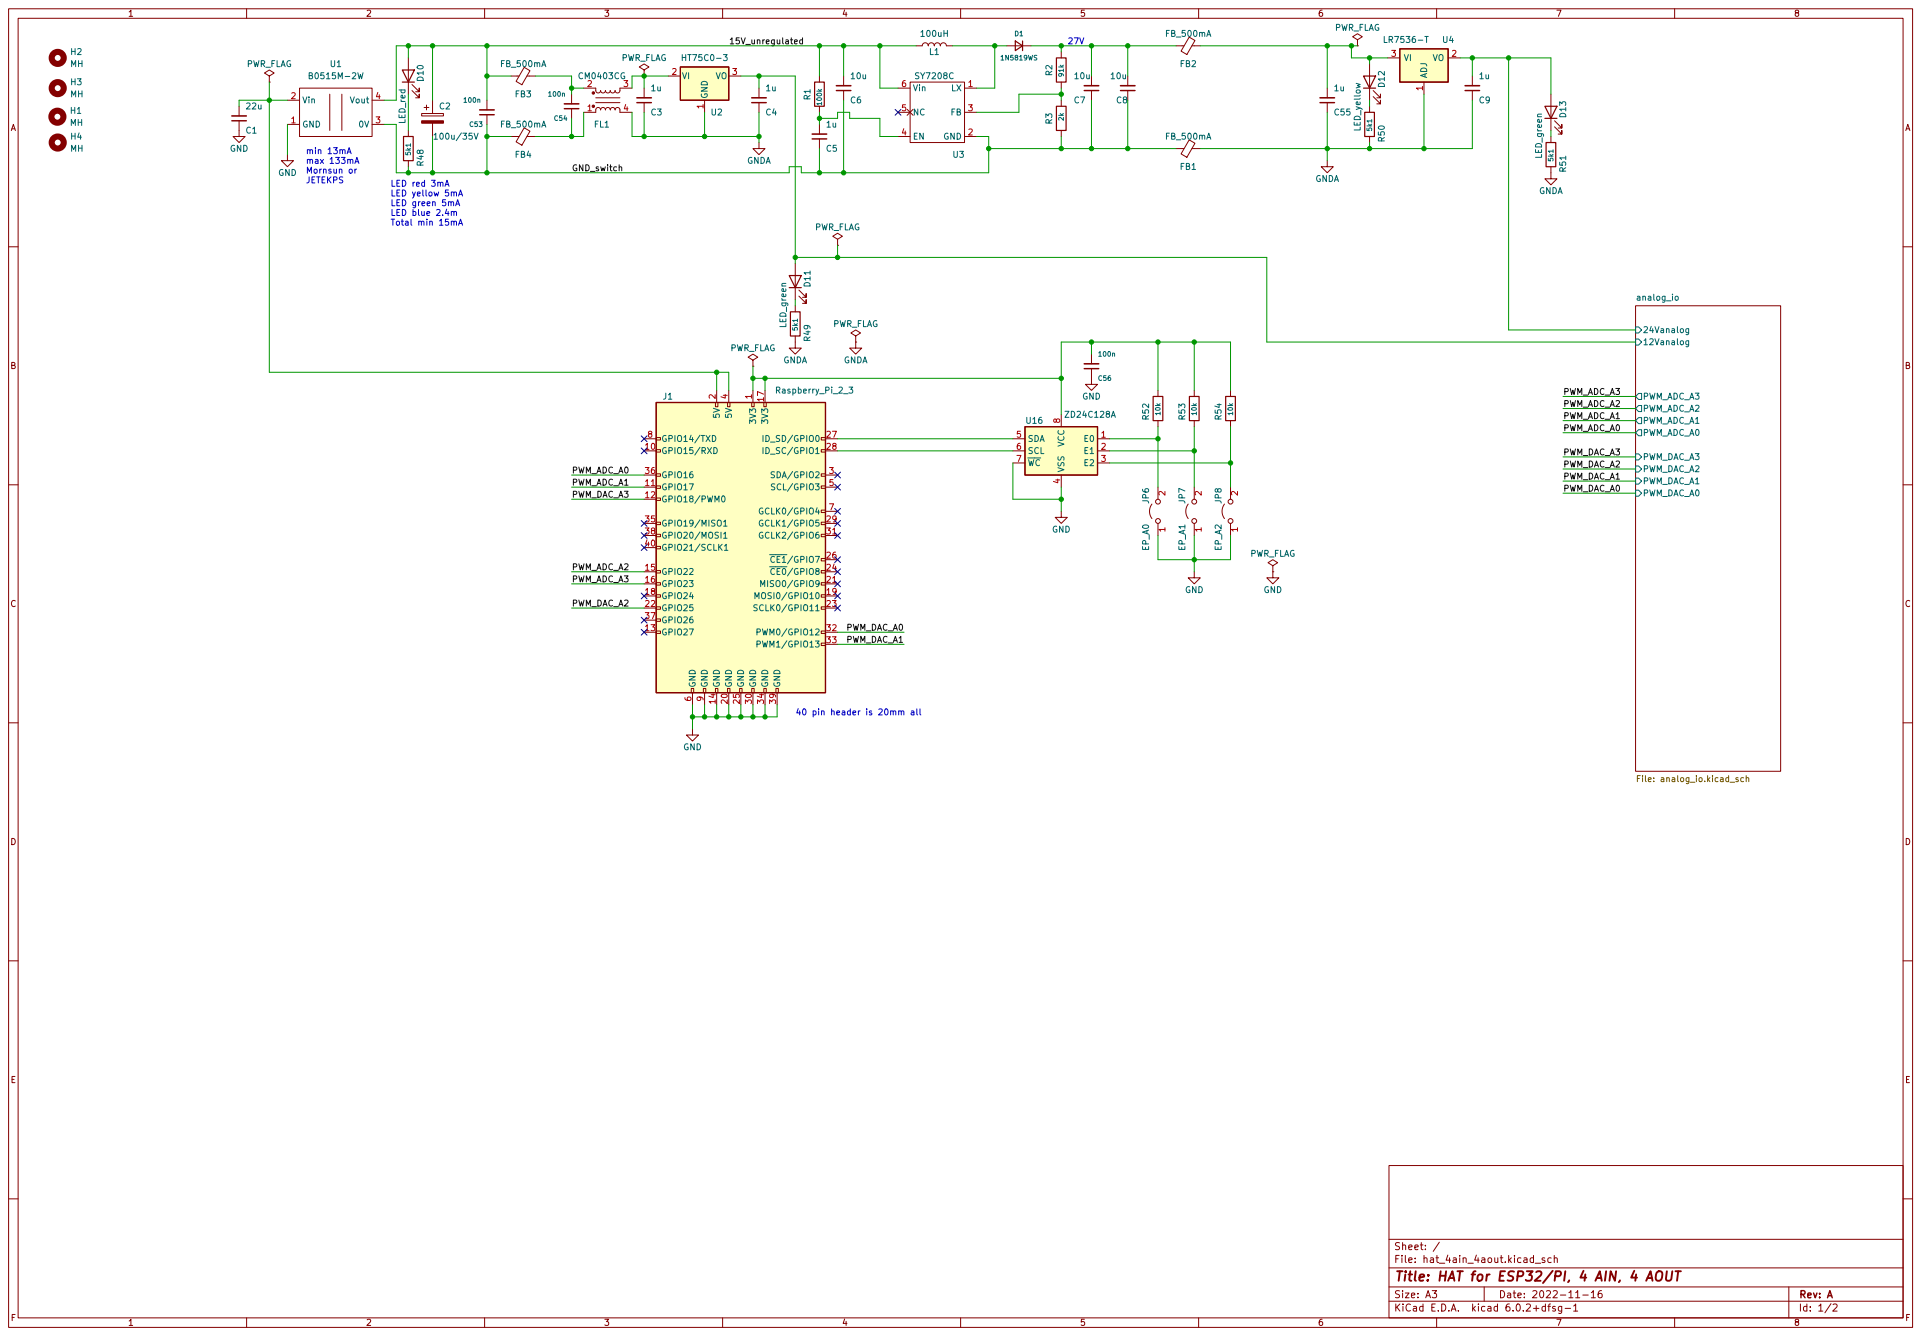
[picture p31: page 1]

min 13mA max 133mA Mornsun or JETEKPS

4 SDA 5 SCL 6 ~{WC} 7 VCC

40 pin header is 20mm all

File: hat_4ain_4aout.kicad_sch Sheet: /
Id: 1/2 Title: HAT for ESP32/PI, 4 AIN, 4 AOUT

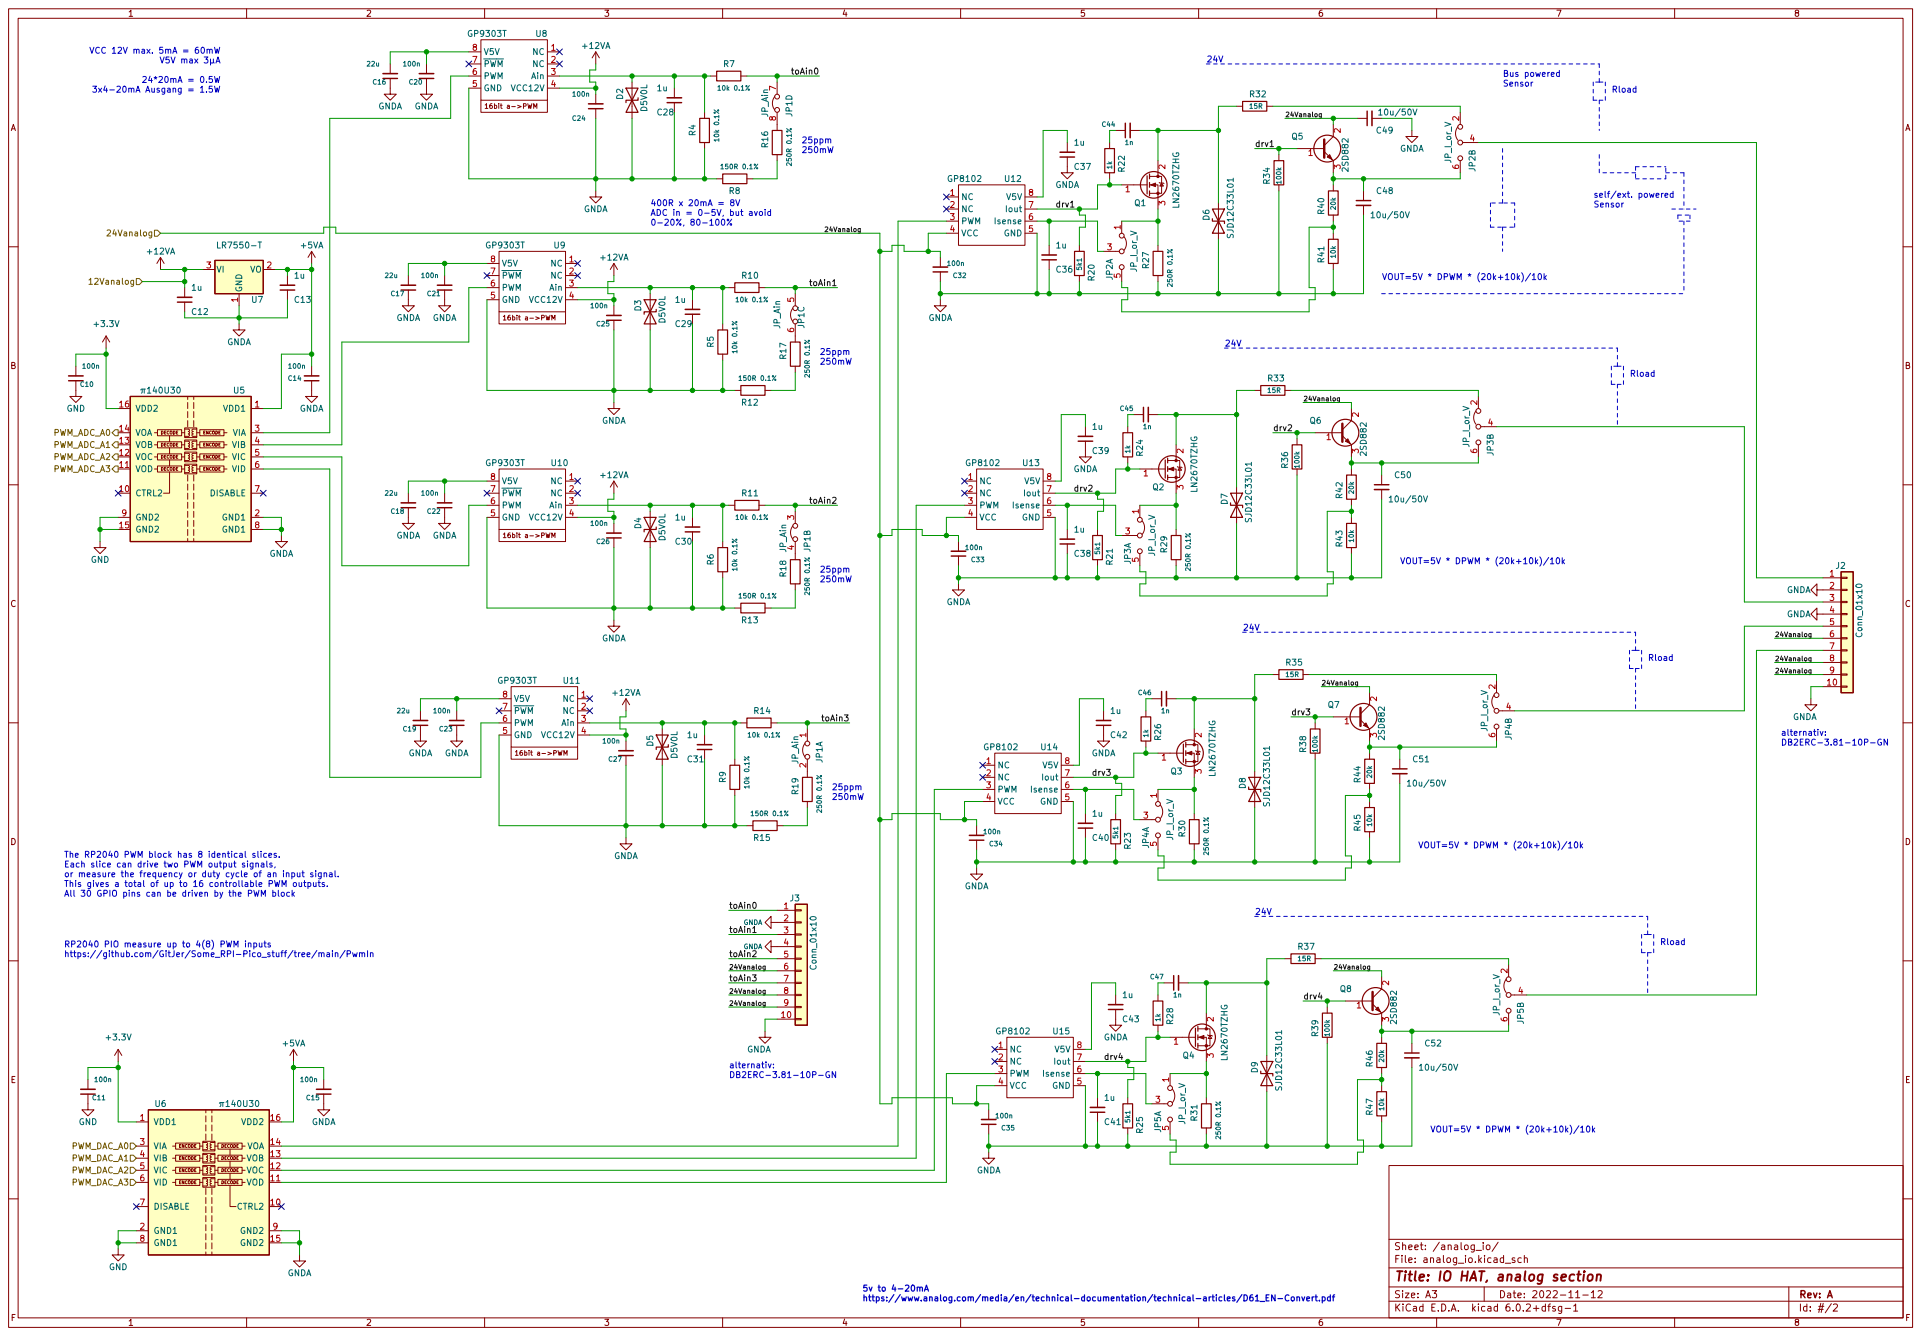
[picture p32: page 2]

self/ext. powered Sensor Bus powered Sensor 24V

DECODE DECODE

VOUT=5V * DPWM * (20k+10k)/10k The RP2040 PWM block has 8 identical slices. Each slice can drive two PWM output signals,

or measure the frequency or duty cycle of an input signal.
This gives a total of up to 16 controllable PWM outputs.

https://github.com/GitJer/Some_RPI-Pico_stuff/tree/main/PwmIn

File: analog_io.kicad_sch
Id: #/2 Title: IO HAT, analog section

https://www.analog.com/media/en/technical-documentation/technical-articles/D61_EN-Convert.pdf

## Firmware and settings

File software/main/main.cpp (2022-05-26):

/*
 * main.cpp
 *
 *  Created on: 26.02.2022
 *      Author: steffen
 *  SPDX-FileCopyrightText: 2022 MDC Service <info@mdc-service.de>
 *  SPDX-License-Identifier: GPL-3.0-or-later
 */


#include "main.h"
#include "sdkconfig.h"

#include "SimplePgSQL.h"
#include "MU80X.h"
#include "HMI.h"
#include "etc.h"
#include "uart.h"
#include "iic.h"
#include "config.h"

// PGSQL
#define PGBufferSize				16384
#define PGCharset					"utf-8"
#define PGUser						"mega"
#define PGPassword					"osteoglossum"
static PGconnection *PGconn;
static unsigned char PGbuffer[PGBufferSize];

// ETC
const char *TAG = "SCALADIS";
//static int cnt = 0;
//static int protcnt = 0;
static int serlen;
static int network_connected = 0;
MU80X *UHF;
HMI *LCD;


unsigned long long ReadAuth(void);

/** ETH */
/**
 * eth_event_handler: Ethernet event handler
 *
 * @param arg argument pointer
 * @param event_base type of the event 
 * @param event_id id of the event
 * @param event_data event data pointer
 */
static void eth_event_handler(void *arg, esp_event_base_t event_base, int32_t event_id, void *event_data) {
	uint8_t mac_addr[6] = { 0 };
	/* we can get the ethernet driver handle from event data */
	esp_eth_handle_t eth_handle = *(esp_eth_handle_t*) event_data;

	switch (event_id) {
	case ETHERNET_EVENT_CONNECTED:
		esp_eth_ioctl(eth_handle, ETH_CMD_G_MAC_ADDR, mac_addr);
		ESP_LOGI(TAG, "Eth Link Up");
		ESP_LOGI(TAG, "Eth MAC %02x:%02x:%02x:%02x:%02x:%02x", mac_addr[0], mac_addr[1], mac_addr[2], mac_addr[3], mac_addr[4], mac_addr[5]);
		break;
	case ETHERNET_EVENT_DISCONNECTED:
		ESP_LOGI(TAG, "Eth Link Down");
		break;
	case ETHERNET_EVENT_START:
		ESP_LOGI(TAG, "Eth Started");
		break;
	case ETHERNET_EVENT_STOP:
		ESP_LOGI(TAG, "Eth Stopped");
		break;
	default:
		break;
	}
}

/**
 * got_ip_event_handler: event called after received the IP address
 *
 * @param arg argument pointer
 * @param event_base type of the event 
 * @param event_id id of the event
 * @param event_data event data pointer
 */
static void got_ip_event_handler(void *arg, esp_event_base_t event_base, int32_t event_id, void *event_data) {
	ip_event_got_ip_t *event = (ip_event_got_ip_t*) event_data;
	const esp_netif_ip_info_t *ip_info = &event->ip_info;

	ESP_LOGI(TAG, "Ethernet Got IP Address");
	ESP_LOGI(TAG, "~~~~~~~~~~~");
	ESP_LOGI(TAG, "ETHIP  :" IPSTR, IP2STR(&ip_info->ip));
	ESP_LOGI(TAG, "ETHMASK:" IPSTR, IP2STR(&ip_info->netmask));
	ESP_LOGI(TAG, "ETHGW  :" IPSTR, IP2STR(&ip_info->gw));
	ESP_LOGI(TAG, "~~~~~~~~~~~");
	network_connected = 1;
}

/**
 * ETH_init: initalize Ethernet
 *
 * @param dhcp to use DHCP, set this to 0
 */
static void ETH_init(int dhcp) {
	ESP_ERROR_CHECK(esp_netif_init());
    ESP_ERROR_CHECK(esp_event_loop_create_default());

    // Create new default instance of esp-netif for Ethernet
    esp_netif_config_t cfg = ESP_NETIF_DEFAULT_ETH();
    esp_netif_t *eth_netif = esp_netif_new(&cfg);

    // Init MAC and PHY configs to default
    eth_mac_config_t mac_config = ETH_MAC_DEFAULT_CONFIG();
    eth_phy_config_t phy_config = ETH_PHY_DEFAULT_CONFIG();

    phy_config.phy_addr = CONFIG_EXAMPLE_ETH_PHY_ADDR;
    phy_config.reset_gpio_num = CONFIG_EXAMPLE_ETH_PHY_RST_GPIO;
    mac_config.smi_mdc_gpio_num = CONFIG_EXAMPLE_ETH_MDC_GPIO;
    mac_config.smi_mdio_gpio_num = CONFIG_EXAMPLE_ETH_MDIO_GPIO;
    esp_eth_mac_t *mac = esp_eth_mac_new_esp32(&mac_config);
    esp_eth_phy_t *phy = esp_eth_phy_new_lan87xx(&phy_config);
    esp_eth_config_t config = ETH_DEFAULT_CONFIG(mac, phy);
    esp_eth_handle_t eth_handle = NULL;
    ESP_ERROR_CHECK(esp_eth_driver_install(&config, &eth_handle));
    ESP_ERROR_CHECK(esp_netif_attach(eth_netif, esp_eth_new_netif_glue(eth_handle)));

	if (dhcp == 0) {
		strcpy(netip, (char*) "192.168.178.32");
		strcpy(netgw, (char*) "192.168.178.1");
		strcpy(netma, (char*) "255.255.255.0");
		strcpy(srvip, (char*) "192.168.178.32");
		srvpo = 5432;
		boxid = 1;
		subbx = 1;
		ReadConfig();

		esp_netif_ip_info_t ip_info;
		memset(&ip_info, 0, sizeof(esp_netif_ip_info_t));
		esp_netif_str_to_ip4((const char*) netip, &ip_info.ip);
		esp_netif_str_to_ip4((const char*) netgw, &ip_info.gw);
		esp_netif_str_to_ip4((const char*) netma, &ip_info.netmask);
		esp_netif_set_ip_info(eth_netif, &ip_info);
	}
	ESP_ERROR_CHECK(esp_eth_start(eth_handle));
}

/** UHF */
/**
 * UHF_init: initalize the Chafon UHF RFID reader
 *
 */
void UHF_init(void) {
	int res;
	UHF = new MU80X(UHF_UART_CHANNEL);
	res = UHF->iSetRFRegion();
	res = UHF->iSetPower(30);
	UHF->DumpBuffer(UHF->RecvBuf, res);
	UHF->iClearBuffer();
}

/**
 * UHF_loop: need to be called regularly, to get notified if RFID-tags inventory change 
 *
 */
void UHF_loop(void) {
	int i;
	unsigned long long ID;
	for (i = 0; i < 1000; i++) {
		if ((ID=ReadAuth())>0) {
			printf("ID:%lld",ID);fflush(stdout);
		}
		UHF->iBufferInventory(7, 0, 10);
		printf("%d -> Tags in Buffer:%d  Tags seen:%d\n", i, UHF->TagsInBuffer,UHF->TagsSeen);
		fflush(stdout);
		vTaskDelay(10);
	};
	while (0) {
		vTaskDelay(100);
	};
}

/**
 * ReadAuth: read authentification
 *
 * @returns Value of the authbuff.
 */
unsigned long long ReadAuth(void) {
	char authbuff[1024];
	char *pos;
	int received = 0;
	int timeout = 60;
	serlen = uart_read_bytes(RDR_UART_CHANNEL, authbuff, 256, 1);
	if (serlen > 0) {

		pos = strchr(authbuff, '\n');
		if (pos) {
			*pos = '\0';
		}

		if (strncmp(authbuff, "CONFIG", 6) == 0) { // we have to receive the init file
			printf("Ready to receive config file !\n");
			fflush(stdout);
			while ((received == 0) & (timeout > 0)) {
				serlen = uart_read_bytes(RDR_UART_CHANNEL, authbuff, 1023, 100);
				if (serlen) {
					authbuff[serlen] = 0;
					WriteConfig(authbuff);
					received = 1;
				} else {
					vTaskDelay(100);
					timeout--;
					printf("TO:%d\n", timeout);
					fflush(stdout);
				}
			}
		}
	}
	authbuff[serlen]=0;
	printf("SERLEN:%d->%s\n", serlen,authbuff);
	fflush(stdout);
	return sscanf("%X",authbuff);
}

/** GPIO **/
/**
 * IO_init: initalize the GPIO
 *
 */
void IO_init(void) {
	// outputs

#define GPO_BIT_MASK (1ULL << PHY_PWR)
	gpio_config_t o_conf;
	o_conf.intr_type = GPIO_INTR_DISABLE;
	o_conf.mode = GPIO_MODE_OUTPUT;
	o_conf.pin_bit_mask = GPO_BIT_MASK;
	o_conf.pull_down_en = GPIO_PULLDOWN_ENABLE;
	o_conf.pull_up_en = GPIO_PULLUP_DISABLE;
	gpio_config(&o_conf);
	gpio_set_level((gpio_num_t) PHY_PWR, 1);

	// inputs
	/*
	 #define GPI_BIT_MASK ((1ULL << SWITCH)|(1ULL << SWITCH))
	 gpio_config_t i_conf;
	 i_conf.intr_type = GPIO_INTR_DISABLE;
	 i_conf.mode = GPIO_MODE_INPUT;
	 i_conf.pin_bit_mask = GPI_BIT_MASK;
	 i_conf.pull_down_en = GPIO_PULLDOWN_DISABLE;
	 i_conf.pull_up_en = GPIO_PULLUP_DISABLE;
	 gpio_config(&i_conf);
	 */
}

/** GPIO **/
/**
 * HMI_init: initalize the HMI
 *
 */
void HMI_init(void) {
	LCD = new HMI(LCD_UART_CHANNEL);
}

/** PGSQL **/
/**
 * PGInit: initalize the PostgreSQL connection
 *
 */
void PGInit(void) {
	PGconn = new PGconnection(0,PGbuffer,PGBufferSize);
}


/**
 * getInfo: functional loop
 *
 */
int getInfo(char *info) {
	int rc, i;
	int pgstat = 0;
	int cnt = 1000;
	char *msg;
	char lbuf[1024];
	rc = PGconn->PGsetDbLogin(srvip, srvpo, dbnam, PGUser, PGPassword, PGCharset);
	printf("Login result:%d\n", rc);
	if (rc < 1)
		return -1;
	pgstat = 1;
	while (cnt > 0) {

		if (pgstat == 1) { // we are connected to srv/db, now we need to rcv the msgs from srv
			rc = PGconn->PGstatus();
			printf("Status:%d\n", rc);
			fflush(stdout);
			if (rc == CONNECTION_BAD || rc == CONNECTION_NEEDED) {
				printf("ERROR: %s", PGconn->PGgetMessage());
				pgstat = -1;
			} else if (rc == CONNECTION_OK) {
				pgstat = 2;
				printf("Ready to submit qry\n");
			}
		}

		if (pgstat == 2) {
			sprintf(lbuf, "SELECT name,gname FROM accounts WHERE id=(cast(x'%s' AS int));", info);
			rc = PGconn->PGexecute(lbuf);
			printf("EXEC result:%d\n", rc);
//                      vTaskDelay(1);
			if (rc == 0) {
				pgstat = 3;
			} else {
				cnt = 0;
			}
		}
		if (pgstat == 3) {
			rc = PGconn->PGgetData();
			//                      printf("RC:%d\n",rc);fflush(stdout);
			if (rc < 0) {
				printf("Get Data Error:%d\n", rc);
				fflush(stdout);
			} else if (rc > 0) {
				if (rc & PG_RSTAT_HAVE_COLUMNS) {
					printf("We got columns !\n");
					fflush(stdout);
					int cols = PGconn->PGnfields();
					printf("Cols: %d\n", cols);
					fflush(stdout);
					/*
					 for (i = 0; i < cols; i++) {
					 if (i) printf(" | ");
					 printf(" %s ",PGconn->PGgetColumn(i));
					 }
					 */
					printf("\n==========\n");
					fflush(stdout);
				} else if (rc & PG_RSTAT_HAVE_ROW) {
					//                                      printf("We got rows !\n");fflush (stdout);
					for (i = 0; i < PGconn->PGnfields(); i++) {
						//                                              if (i) printf(" | ");
						//                                              msg = PGconn->PGgetValue(i);
						sprintf(lbuf, "Info:\r\n%s\r\n%s", PGconn->PGgetValue(1), PGconn->PGgetValue(0));
						//                                              if (!msg) msg = (char *) "NULL";
						//                                              printf(" %s", msg);fflush(stdout);
					}
					//                                      printf("\n");fflush(stdout);
				} else if (rc & PG_RSTAT_HAVE_SUMMARY) {
					printf("Rows affected: ");
					printf("%d\n", PGconn->PGntuples());
				} else if (rc & PG_RSTAT_HAVE_MESSAGE) {
					printf("We got msg !\n");
					fflush(stdout);
					msg = PGconn->PGgetMessage();
					if (!msg)
						msg = (char*) "NULL";
					printf("MSG: %s\n", msg);
					fflush(stdout);
				}
				if (rc & PG_RSTAT_READY) {
					printf("We made it !\n");
					fflush(stdout);
					cnt = 0;
					break;
				}
			}
		} // pgstat==3
		vTaskDelay(1);
		cnt--;
	} // while (cnt>0)
	PGconn->PGclose();
	return rc;
}

/**
 * init: initialize all modules
 *
 */
static void init(void) {
//	int res;
//	printf("UART-Init:\n\n");
//	UART_init();
//	printf("IO-Init:\n\n");
//	IO_init();
//	printf("ETH-Init:\n\n");
//	ETH_init(0);
//	printf("UHF-Init:\n\n");
//	UHF_init();
//	printf("HMI-Init:\n\n");
//	HMI_init();
	printf("I2C-Init:\n\n");
	ESP_ERROR_CHECK(I2C_init());
//	printf("ADC-Init:\n\n");
//	ESP_ERROR_CHECK(ADC_init());
	ESP_LOGI(TAG, "I2C initialized successfully");

}

/**
 * main_loop: 
 *
 */
static void main_loop() {
	int res1 = 0, res2 = 0;
	printf("Main loop\n");
	fflush(stdout);
//	res1 = LCD->iSendProt(6, (char*) "page 0", 1);
	printf("res:%d\n", res1);
	fflush(stdout);
//	int door=1;

//	UHF_loop();
//	EditConfig();
//	UHF_loop();

	while (1) {
//		ADCReadAll();

		I2C_buf[0] = 0x02;	// write data to output port 1
		I2C_buf[1] = 0x55;	// write data to output port 1
		I2C_buf[2] = 0xAA;	// write data to output port 1
		res1 = i2c_master_write_to_device(I2C_MASTER_NUM, I2C_PORTEXP1, I2C_buf, 3, I2C_MASTER_TIMEOUT_MS / portTICK_PERIOD_MS);
	//	printf("\nI2C wrote 0x%02X%02X: %d\n", I2C_buf[0], I2C_buf[1], res1);
//		I2C_buf[0] = 0x00;	// lese 3 bytes
//		res2 = i2c_master_read_from_device(I2C_MASTER_NUM, I2C_PORTEXP1, I2C_buf, 1, I2C_MASTER_TIMEOUT_MS / portTICK_PERIOD_MS);

		printf("\nMaster wrote %d %d %02X\n", res1,res2,I2C_buf[0]);


		vTaskDelay(500 / portTICK_PERIOD_MS);
		I2C_buf[0] = 0x02;	// write data to output port 1
		I2C_buf[1] = 0xAA;	// write data to output port 1
		I2C_buf[2] = 0x55;	// write data to output port 1
		res1 = i2c_master_write_to_device(I2C_MASTER_NUM, I2C_PORTEXP1, I2C_buf, 3, I2C_MASTER_TIMEOUT_MS / portTICK_PERIOD_MS);
	//	printf("\nI2C wrote 0x%02X%02X: %d\n", I2C_buf[0], I2C_buf[1], res1);
//		I2C_buf[0] = 0x00;	// lese 3 bytes
//		res2 = i2c_master_read_from_device(I2C_MASTER_NUM, I2C_PORTEXP1, I2C_buf, 1, I2C_MASTER_TIMEOUT_MS / portTICK_PERIOD_MS);

		printf("\nMaster wrote %d %d %02X\n", res1,res2,I2C_buf[0]);


		vTaskDelay(500 / portTICK_PERIOD_MS);
	}

	while (0) {
		printf("Closed 1:%d\n",DoorIsClosed(LOCK1R));fflush(stdout);
		printf("Closed 2:%d\n",DoorIsClosed(LOCK2R));fflush(stdout);
		printf("Closed 3:%d\n",DoorIsClosed(LOCK3R));fflush(stdout);
		printf("Closed 4:%d\n",DoorIsClosed(LOCK4R));fflush(stdout);
		/*
		res1 = i2c_master_write_to_device(I2C_MASTER_NUM, I2C_PORTEXP, I2C_buf, 2, I2C_MASTER_TIMEOUT_MS / portTICK_PERIOD_MS);
		printf("\nI2C wrote 0x%02X%02X: %d\n", I2C_buf[0], I2C_buf[1], res1);

		vTaskDelay(1);

		I2C_buf[0] = 0x05;
		I2C_buf[1] = 0x00;
		res1 = i2c_master_write_to_device(I2C_MASTER_NUM, I2C_PORTEXP, I2C_buf, 2, I2C_MASTER_TIMEOUT_MS / portTICK_PERIOD_MS);
		printf("\nI2C wrote 0x%02X%02X: %d\n", I2C_buf[0], I2C_buf[1], res1);

		I2C_buf[0] = 0x80;	// Setze CMD read port 0
		I2C_buf[1] = 0x00;
		I2C_buf[2] = 0x00;
		res1 = i2c_master_write_to_device(I2C_MASTER_NUM, I2C_PORTEXP, I2C_buf, 1, I2C_MASTER_TIMEOUT_MS / portTICK_PERIOD_MS);
		printf("\nI2C wrote 0x%02X%02X: %d\n", I2C_buf[0], I2C_buf[1], res1);
		I2C_buf[0] = 0x00;	// lese 3 bytes
		res2 = i2c_master_read_from_device(I2C_MASTER_NUM, I2C_PORTEXP, I2C_buf, 3, I2C_MASTER_TIMEOUT_MS / portTICK_PERIOD_MS);
		printf("\nI2C read 0x %02X %02X  %02X: %d\n", I2C_buf[0], I2C_buf[1], I2C_buf[2], res2);
		vTaskDelay(2000 / portTICK_PERIOD_MS);
		printf(" #:S%d R:%d ", res1, res2);
		fflush(stdout);
		*/

		vTaskDelay(10000 / portTICK_PERIOD_MS);
		DoorOpen(1);
//		vTaskDelay(10);
		DoorOpen(2);
		vTaskDelay(10);
		DoorOpen(3);
		vTaskDelay(10);
		DoorOpen(4);
		vTaskDelay(10);
		printf("\n\n\n");fflush(stdout);
	}
}

extern "C" {
void app_main(void) {
	init();
	main_loop();
}
}

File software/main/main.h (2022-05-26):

/*
 * main.h
 *
 *  Created on: 26.02.2022
 *      Author: steffen
 *  SPDX-FileCopyrightText: 2022 MDC Service <info@mdc-service.de>
 *  SPDX-License-Identifier: GPL-3.0-or-later
 */


#ifndef MAIN_MAIN_H_
#define MAIN_MAIN_H_
#include <sys/types.h>
#include <stdio.h>
#include <string.h>
#include <stdint.h>
#include <freertos/FreeRTOS.h>
#include <freertos/task.h>
#include <esp_netif.h>
#include <esp_eth.h>
#include <esp_log.h>
#include <esp_spiffs.h>
#include <esp_err.h>
#include <driver/uart.h>
#include <driver/gpio.h>
#include <driver/i2c.h>
#include <lwip/err.h>
#include <lwip/sockets.h>


//    +3,3V              				// Pin 1
//    GND                				// Pin 2
//    ESP_EN              				// Pin 3
#define UHF_RXD_MISO  		36  		// pin 4	UART
#define LCD_RXD_MISO  		39  		// pin 5	UART
// NC pin 6
#define I2Cint				35	  		// pin 7	EXP
#define SCL			  		32 			// pin 8	EXP
#define SDA			  		33 			// pin 9	EXP
#define EMAC_RXD0_RMII 		25 			// pin 10   ETH
#define EMAC_RXD1_RMII  	26  		// pin 11   ETH
#define EMAC_RX_CRS_DV  	27  		// pin 12   ETH
#define HS2_CLK  			14  		// pin 13   ETH
#define PHY_PWR  			12  		// pin 14   ETH
//  									// pin 15	GND
#define I2C_SDA_40p			13  		// pin 16	40p
// NC pin 17 bis 22
#define HS2_CMD  			15  		// pin 23   ETH
#define HS2_DATA0  			02  		// pin 24   ETH
#define ETH_CLKREF 			0 			// pin 25   ETH
#define UHF_TXD_MOSI 		04  		// pin 26	UART
#define LCD_TXD_MOSI 		16  		// pin 27	UART
#define EMAC_CLK_OUT_180  	17 			// pin 28   ETH
#define SPI_CS  			05  		// pin 29	40p
#define MDIO_RMII  			18			// pin 30	ETH
#define EMAC_TXD0_RMII		19  		// pin 31	ETH
//NC pin 32
#define EMAC_TX_EN_RMII  	21  		// pin 33	ETH
#define RDR_RXD_MISO  		03  		// pin 34	UART
#define RDR_TXD_MOSI  		01  		// pin 35	UART
#define EMAC_TXD1_RMII  	22  		// pin 36	ETH
#define MDC_RMII  			23			// pin 37	ETH
//GND pin 38, 39
#define RDR_UART_CHANNEL			0
#define RDR_UART_BAUD_RATE     		9600
//#define RDR_UART_BAUD_RATE     		115200
#define RDR_UART_RX_PIN				RDR_RXD_MISO
#define RDR_UART_TX_PIN				RDR_TXD_MOSI

#define LCD_UART_CHANNEL			1
#define LCD_UART_BAUD_RATE     		115200
#define LCD_UART_RX_PIN				LCD_RXD_MISO
#define LCD_UART_TX_PIN				LCD_TXD_MOSI

#define UHF_UART_CHANNEL			2	// for easy adaptation in the future
#define UHF_UART_BAUD_RATE        	115200
#define UHF_UART_RX_PIN				UHF_RXD_MISO
#define UHF_UART_TX_PIN				UHF_TXD_MOSI

#define I2C_MASTER_SCL_IO			SCL
#define I2C_MASTER_SDA_IO           SDA
#define I2C_MASTER_NUM              0                          /*!< I2C master i2c port number, the number of i2c peripheral interfaces available will depend on the chip */
#define I2C_MASTER_FREQ_HZ          100000                     /*!< I2C master clock frequency */
#define I2C_MASTER_TX_BUF_DISABLE   0                          /*!< I2C master doesn't need buffer */
#define I2C_MASTER_RX_BUF_DISABLE   0                          /*!< I2C master doesn't need buffer */
#define I2C_MASTER_TIMEOUT_MS       1000

#define I2C_PORTEXP1				0x58
#define I2C_PORTEXP2				0x5A

#define ADC_DEFAULT_IIC_ADDR 		0x48
#define ADC_CHAN_NUM 				8
#define ADC_REG_RAW_DATA_START 		0x10
#define ADC_REG_VOL_START 			0x20
#define ADC_REG_RTO_START 			0x30
#define ADC_REG_SET_ADDR 			0xC0

// GPA	Output
// GPB  Input

#define LOCK1						0x40
#define LOCK2						0x10
#define LOCK3						0x20
#define LOCK4						0x80
#define LOCK_MASK					LOCK1+LOCK2+LOCK3+LOCK4
#define LOCKPORT					0x01

#define LOCK1R						0x04
#define LOCK2R						0x01
#define LOCK3R						0x02
#define LOCK4R						0x08
#define LOCKR_MASK					LOCK1R+LOCK2R+LOCK3R+LOCK4R
#define LOCKR_PORT					0x02

#define TASK_STACK_SIZE         	2048
#define READ_BUF_SIZE           	1024

#define STX	0x02
#define ETX 0x03
#define EOT 0x04

#define MAX_TAGS 256

typedef struct {
  unsigned char b[12];
  unsigned char ant;
  unsigned char rssi;
  unsigned char count;
} Tag_t;




#endif /* MAIN_MAIN_H_ */

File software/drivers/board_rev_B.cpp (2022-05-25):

/*
 * board_rev_B.cpp
 *
 *  Created on: 26.02.2022
 *      Author: michi
 *  SPDX-FileCopyrightText: 2022 MDC Service <info@mdc-service.de>
 *  SPDX-License-Identifier: GPL-3.0-or-later
 */


#include <stdio.h>
#include <string.h>
#include <stdlib.h>
#include "freertos/FreeRTOS.h"
#include "freertos/task.h"
#include "freertos/queue.h"
#include "driver/gpio.h"
#include "driver/i2c.h"
#include "schrank_ant_pcb.h" //contains setting of board revision

#ifdef ESP32_BOARD_REV_B
#include "board_rev_B.hpp"

/**
 * io_init: initalize Rev. B boards
 *
 */

void io_init(void)
{
	#define GPO_BIT_MASK 0 //we dont have GPIO as outputs, all output is done via I2C Port Expander
/* as we have not ouput, leave default settings
	gpio_config_t o_conf;
	o_conf.intr_type = GPIO_INTR_DISABLE;
	o_conf.mode = GPIO_MODE_OUTPUT;
	o_conf.pin_bit_mask = GPO_BIT_MASK;
	o_conf.pull_down_en = GPIO_PULLDOWN_ENABLE;
	o_conf.pull_up_en = GPIO_PULLUP_DISABLE;
	gpio_config(&o_conf);
*/	
	//gpio_set_level((gpio_num_t) PHY_PWR, 1);

	// inputs

	#define IRQ2Esp 34
	#define I2Cext_INT 35
	 #define GPI_BIT_MASK ((1ULL<<IRQ2Esp) | (1ULL<<I2Cext_INT)) 
	 //io_conf.pin_bit_mask = (1ULL<<15);//bit mask of the pins that you want to set,e.g.GPIO15
	 gpio_config_t i_conf;
	 i_conf.intr_type = GPIO_INTR_DISABLE;
	 i_conf.mode = GPIO_MODE_INPUT;
	 i_conf.pin_bit_mask = GPI_BIT_MASK;
	 i_conf.pull_down_en = GPIO_PULLDOWN_DISABLE;
	 i_conf.pull_up_en = GPIO_PULLUP_DISABLE;
	 gpio_config(&i_conf);
	 
}




esp_err_t i2c_init(void) {	
	int res1,res2;
	int I2C_master_port = I2C_MASTER_NUM;
	uint8_t I2C_buf[5];
	i2c_config_t I2C_conf = { .mode = I2C_MODE_MASTER, .sda_io_num = I2C_MASTER_SDA_IO, .scl_io_num = I2C_MASTER_SCL_IO, .sda_pullup_en = GPIO_PULLUP_ENABLE, .scl_pullup_en = GPIO_PULLUP_ENABLE, .master { .clk_speed = I2C_MASTER_FREQ_HZ, } };
	i2c_param_config(I2C_master_port, &I2C_conf);
		
	printf("\nInstall i2c_driver: Mode=%d sda_io_num=%d scl_io_num=%d\n", I2C_MODE_MASTER, I2C_MASTER_SDA_IO, I2C_MASTER_SCL_IO);
	res1=i2c_driver_install(I2C_master_port, I2C_conf.mode,
	I2C_MASTER_RX_BUF_DISABLE, I2C_MASTER_TX_BUF_DISABLE, 0);	
	ESP_ERROR_CHECK_WITHOUT_ABORT(res1);
	printf("After i2c_driver_install\n");
	vTaskDelay(500 / portTICK_PERIOD_MS);

//1. Init AW9523 on address 0x00
	I2C_buf[0] = 0x7F;	// write to AW9523 Soft Reset register
	I2C_buf[1] = 0x00;	// write data to output port 1
	I2C_buf[2] = 0x00;	// write data to output port 1
	printf("I2C write to bus %d to I2C-Adress %d byte0 = %d byte 1 = %d\n", I2C_MASTER_NUM, I2C_PORTEXP1, I2C_buf[0], I2C_buf[1] );
	res1 = i2c_master_write_to_device(I2C_MASTER_NUM, I2C_PORTEXP1, I2C_buf, 3, I2C_MASTER_TIMEOUT_MS / portTICK_PERIOD_MS);
	printf("I2C write to bus %d to I2C-Adress %d byte0 = %d byte 1 = %d\n", I2C_MASTER_NUM, I2C_PORTEXP2, I2C_buf[0], I2C_buf[1] );
	res2 = i2c_master_write_to_device(I2C_MASTER_NUM, I2C_PORTEXP2, I2C_buf, 3, I2C_MASTER_TIMEOUT_MS / portTICK_PERIOD_MS);
	printf("\nMaster wrote %d %d %02X\n", res1,res2,I2C_buf[0]);
	printf("After AW9523 soft-RESET\n");
	vTaskDelay(500 / portTICK_PERIOD_MS);

//2. Set outputs push pull in AW9523 Global Control Register	
	I2C_buf[0] = 0x11;	// write data to Global Control Register
	I2C_buf[1] = 0x10;	// write data to Global Control Register, set Bit4 to Push Pull
	res1 = i2c_master_write_to_device(I2C_MASTER_NUM, I2C_PORTEXP1, I2C_buf, 2, I2C_MASTER_TIMEOUT_MS / portTICK_PERIOD_MS);
	res2 = i2c_master_write_to_device(I2C_MASTER_NUM, I2C_PORTEXP2, I2C_buf, 2, I2C_MASTER_TIMEOUT_MS / portTICK_PERIOD_MS);
	printf("\nMaster wrote %d %d %02X\n", res1,res2,I2C_buf[0]);		

	I2C_buf[0] = 0x02;	// write data to output port 1
	I2C_buf[1] = 0xFF;	// write data to output port 1
	I2C_buf[2] = 0xFF;	// write data to output port 1
	I2C_buf[3] = 0x00;	// write data to output port 1
	I2C_buf[4] = 0x00;	// write data to output port 1
	res1 = i2c_master_write_to_device(I2C_MASTER_NUM, I2C_PORTEXP1, I2C_buf, 5, I2C_MASTER_TIMEOUT_MS / portTICK_PERIOD_MS);
	res2 = i2c_master_write_to_device(I2C_MASTER_NUM, I2C_PORTEXP2, I2C_buf, 5, I2C_MASTER_TIMEOUT_MS / portTICK_PERIOD_MS);
	printf("\nMaster wrote %d %d %02X\n", res1,res2,I2C_buf[0]);
	printf("After AW9523 all GPIOs HIGH\n");
	vTaskDelay(500 / portTICK_PERIOD_MS);


	
//2. Set AW9523-PhyPower to high	
/*	I2C_buf[0] = 0x02;	// write to register 0x02
	I2C_buf[1] = 255;	// set all pins high
	I2C_buf[2] = 255;	// set all pins high
	res1 = i2c_master_write_to_device(I2C_MASTER_NUM, I2C_PORTEXP2, I2C_buf, 3, I2C_MASTER_TIMEOUT_MS / portTICK_PERIOD_MS);	
*/	
	return res1;
}

#endif

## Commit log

2022-05-23 initaial check in EsPiFF V2 files
    [ESP32_RaspiFF_LAN8720ETH_V2.csv, ESP32_RaspiFF_LAN8720ETH_V2.kicad_pcb, ESP32_RaspiFF_LAN8720ETH_V2.kicad_sch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]
2022-05-23 initial check in firmware files
    [partitions.csv]
2022-05-24 add photo of opend HMI enclosure
2022-05-25 replace files with copyright header and Doxygen comments
    [partitions.csv]
2022-05-25 added drivers in own folder
2022-05-25 add project files for root folder
    [partitions.csv]
2022-05-26 initial check in Cafon UHF RFID driver for the MU80x series
2022-05-26 move MU80x to drivers
2022-05-26 moved MU80 from libs to drivers
2022-05-26 check in SD-card drivers and test
2022-05-26 Initial check in HMI driver
2022-06-22 Update Readme, fix some typos, add V3 board picture
2022-06-22 change board-v3 picture
2022-06-22 add picture for V2 board
2022-07-20 initial check in V3 schematic and PCB rendering
2022-07-20 re-uploaded V3 schematic after correcting typos
2022-10-01 removed V3.0 hardware folder, replace by V3.1
    [ESP32_RaspiFF_LAN8720ETH_V2.csv, ESP32_RaspiFF_LAN8720ETH_V2.kicad_pcb, ESP32_RaspiFF_LAN8720ETH_V2.kicad_sch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]
2022-10-01 Upload V3.1 final version
    [espiff_v3_1.csv, espiff_v3_1.kicad_sch, ethernet.kicad_sch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]
2022-10-27 add info about not use the PCB antenna,
    but an external antenna instead
2022-11-09 change to datasheet version 0.3
    added info about the cable set, color code of cables, pinout
2022-11-16 Update README.md
    added details to the communication between ESP32 and RP2040
2022-11-23 update ESP32 to RP2040 interconnection
2022-11-24 add PCB antenna news
